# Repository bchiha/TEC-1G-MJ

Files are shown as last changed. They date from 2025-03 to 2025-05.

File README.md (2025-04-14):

## File Links
| File | Description | Version |
|---|---|---|
| [Errata](./Errata.md) | <b>*CRITICAL:*</b> The latest Errata announcements. **Read BEFORE assembly!** | 2/jun/2024 |
| [Assembly Instructions](./Documentation/Assembly/Readme.md) | Instructions on putting the TEC-1G together | 0.2 |
| [Component Overlay](./TEC-1G_Component_Overlay_v1-21.pdf) | Searchable PDF for component placement. | 1.21 |
| [Parts List](./TEC-1G_PartsList_v1-5.pdf) | (Out of date. Needs updating. Use with caution. Always follow schematic.) | 1.5 |
| [BOM Sourcing](./files/TEC-1G_BOM_v1.5.xlsx) | (Out of date. Needs updating. Use with caution. Always follow schematic.) | 1.5 |
| [Schematic](./TEC-1G_Schematic_v1-22.pdf) | See what makes the TEC-1G tick. | 1.22 |
| [PCB Gerbers](./TEC-1G_Gerbers_v1-22_SigEd.zip) | Gerbers of the PCB so you can print your own! | 1.22 |
| [Monitors / ROMs](./ROMs/) | Download and burn the ROMs for your TEC-1G from this link! | 1.5 |
| [MON3 User Guide](./MON3_User_Guide_v1.5.pdf) | The comprehensive User Guide to MON3 | 1.5 |
| [TEC Deck](./TEC-Deck/) | The TEC Deck has multiple Cards that add major functionalityto the TEC-1G! | 1.2 |
| [GPIO Modules](./GPIO/) | See what modules can be attached to the GPIO connector on the LHS of the TEC-1G | 1.0 |
| [TEC Expander](./Expander/) | The Expander finally has the 8x8 LED Array... And it's in RGB! | 1.0 |

## News & Developments

We have added a new section to the GitHub that agregates all the news and new items for the TEC-1G. [Follow this link](https://github.com/MarkJelic/TEC-1G/tree/main/News) for all the latest info.

# TEC-1G Introduction

TEC-1G - A Z80 based single board computer.

The TEC-1G is a direct descendant of the Talking Electronics Computer, known as the TEC-1, which was first published by the Australian electronics hobbyist magazine ["Talking Electronics"](https://www.talkingelectronics.com/te_interactive_index.html) (or simply TE), between 1981 and 1991.

The TEC-1 was developed as a learning computer, designed to teach the basics of how a microprocessor works at the fundamental hardware and software level, and offered the ability to create and run simple programs in Z80 machine code. TE magazine covered the TEC-1 in six installments, known as "Issue 10" to "Issue 15". These magazines can be downloaded freely from the TEC-1 GitHub, located at [tec1group/TE-Magazines](https://github.com/tec1group/TE-Magazines)

Interest in the TEC-1 declined following the winding down of TE through the 1990's, which reflected a general decline in electronics as a hobby in Australia. This, coupled with interest in more advanced 'single chip' microcontrollers saw TEC-1's put aside and the world moved on.

The TEC-1 was revived around 2018 with a release of a reproduction PCB and related peripherals on the Internet. Retro computing has become quite popular of late, and so a an active TEC community has (re)formed through [Facebook](https://www.facebook.com/groups/tec1z80) with new hardware designs, enhanced versions and various expansion options being offered by various contributors within the community.

The 1G builds on both the TEC-1's base and recent history to modernize the overall design, address various design limitations and integrate many of the excellent add-ons into to a single PCB for the first time.

The TEC-1G remains true to the original TE design goals: it is is built using only simple through-hole TTL logic chips so it is easily built and understood by the hobbyist. For the first time, the TEC-1G will also be fully free and open source, in both its hardware and software. The TEC-1G is the ultimate TEC-1!

The 1G has been developed by Mark Jelic with the input of the original designers, John Hardy and Ken Stone, ex-TE staff member Craig Hart, along with contributions from community members Brian Chiha and Ian McLean. Finally, the 1G has also been produced with the blessing of Colin Mitchell, Talking Electronics owner.

## Major Features

- Full TEC-1 hardware and software compatability; runs all previous MONitors without modification
- Flexible memory options; 32K RAM, 16k ROM in default configuration. Up to 64k RAM + 16k ROM supported.
- Support for multiple configuration options and memory types from 2k to 32k memory devices
- RAM write protection for improved software development
- Shadow Memory and bank switching capabilities
- 20x4 LCD screen as primary display device
- Diagnostic & LED bar indicator for system state
- Z80A CPU running at 4.0MHz; 'slow' clock support for older monitors retained
- Full QWERTY MATRIX keyboard & joystick options
- Upgraded key options for onboard hex keypad; supports Gateron Low Profile switches with optional backlighting, as well as standard 12mm tactile buttons
- Improved RESET circuit for reliable start up and system stability
- USB B or 9-12v AC/DC power sources
- Serial interface using an optional FTDI/FT232 adaptor for USB communication with a PC or terminal
- Future support for SD card mass storage interface
- Native Z-80 expansion bus connectors supporting a full range of peripherals
- 'TEC-Deck' expansion connectors for future daughterboards
- 'TEC Expander' port for compatability with existing TEC peripherals
- HALT status LED

## More Documentation [Coming Soon™](/Documentation/readme.md)

TEC-1G Render - Gateron Keys

I'd like to thank PCBWay for sponsoring the ongoing development of modules that are being added to the TEC-1G ecosystem. I'm impressed how proactive they are in finding projects like this one and encourage and foster such development. Thank you, PCBWay!

PCBWay Logo

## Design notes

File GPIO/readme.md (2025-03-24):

# TEC-1G GPIO Connector

## Expansion Modules available for the GPIO Connector
| Module | Description | Version |
|---|---|---|
| [GPIO Protoboard](./Protoboard/) | The protoboard gerbers & design files - Use as a Template!  | 1.3 |
| [GPIO SD Card](./SD-Card/) | Micro SD-Card interface, as well as a general purpose 8Bit input/output board | 1.3 |
| [GPIO RTC](./RTC/) | Real Time Clock and Parameter RAM  | 1.3 |
| [GPIO Printer](./Printer/) | Parallel Printer Interface, and a general purpose 8Bit input/output board  | 1.3 |
| [GPIO New Board!](./) | Add your guesses to the "New GPIO Board" Issue for a chance to win a free kit!  | 1.3 |

#### Adding General Purpose Input/Output capabilities to the TEC-1G, easily.

Version 1.3 of the GPIO connector adds 4 pins to the original 16!

2 pins are spare and can be used by the user for anything they want to propagate up the GPIO stack.

We have also added the Transmit and Receive lines as used by the FTDI module.

These have been added for a NEW board, Coming Soon (tm)!

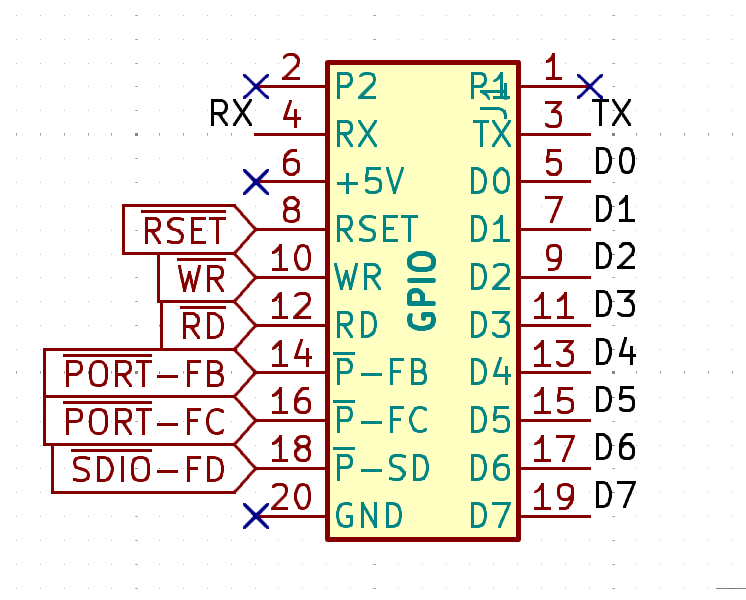
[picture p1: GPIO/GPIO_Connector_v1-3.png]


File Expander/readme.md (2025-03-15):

# TEC Expander

## Expansion Modules available for the TEC Expander
| Module | Description | Version |
|---|---|---|
| [RGB 8x8 Array](./8x8/) | The brand new 8x8 LED Array in full RGB!!  | 1.2 |

The easy way to attach your favourite expansions.



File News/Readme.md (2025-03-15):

# TEC-1G News
--------------------------------------------------------
## Signature Edition Gerbers Released! (15/Mar/2025)
The Signature Edition of the TEC-1G PCB is the final version of the TEC-1G PCB to be released.
The Gerbers can now be downloaded from the root directory of the Repo.

--------------------------------------------------------
## ODE to TEC-1G Song! (12/Mar/2025)
Ken Stone has applied his masterful Musical and AI-Wrangling skills to turn John's poem into a catchy song!

https://github.com/MarkJelic/TEC-1G/blob/main/News/ODE_to_TEC-1G_by_John_Melville_(Ken_Stone).m4a

--------------------------------------------------------
## ODE to TEC-1G by John Melville (11/Mar/2025)
John has penned a brilliant poem about the 1G. Check it out:

https://github.com/MarkJelic/TEC-1G/blob/main/News/Ode_to_1G.md

--------------------------------------------------------
## TEC-1G RGB 8x8 Display (10/Mar/2025)
The first add-on ever developed for the original TEC-1 was an LED 8x8 Matrix Display. 40 years later and the same idea has had new life breathed into it with a full colour RGB module in the tidiest PCB yet design for the 1G, that allows for up to 3 modules chained together. Check the details at<br>

https://github.com/MarkJelic/TEC-1G/tree/main/Expander/8x8

--------------------------------------------------------
## TEC-1G Font Identified! (24/Jun/2024)
The mystery of which font goes into making the iconic TEC-1G logo has been solved by James Elphick.  At first we thought it might have been Posterama 1984 but that is owned by one of the oldest font foundry, Monotype.  James soon found a very close competitor in Montserrat-Alt1 and it is an Open Font typeface.  So in aligning with our ethos, we must have used the Open Source version and we have copied it to this GitHub, in the \Assets folder off the root:<br>

https://github.com/MarkJelic/TEC-1G/tree/main/Assets

--------------------------------------------------------
## Fullisik Mechanical Matrix Keyboard Released! (18/Jun/2024)
Designed by James Elphick, following the design of the Tactile Matrix keyboard, the new Fullisik Mechanical Matrix Keyboard goes on sale today, and is sold out befor the weekend is done! Looks and feels fantastic.

--------------------------------------------------------

## MON3 version 1.5 (7/Jun/2024)
Monitor3 has been upgraded to version 1.5 by Brian Chiha. Get all the details here:<br>
https://github.com/MarkJelic/TEC-1G/tree/main/ROMs/MON3

--------------------------------------------------------
## 7 Segment Bezel by "Fred Nichols" (3/May/2024)

Now this is really cool! Fred Nichols has created a 3D printable Bezel that sits over the 7 segment displays. He has kindly released the STL files so you can download it and print it yourself or get a shop to do that for you. Either way, it makes the TEC-1G look really fancy! [Click on this link](https://github.com/turbo-gecko/TEC/tree/main/3D%20Printing/7%20Seg%20Bezel) to take you to his GitHub!

7Seg Bezel 3 Piece Lit

--------------------------------------------------------
## Dedicated TEC-1G Video Channel Launched (27/Apr/2024)
Yes, we know the documentation isn't complete, and even if it were, there are many amongst us that don't do well learning anything by reading text on a screen. Some of us (raises hand) are visual learners and so videos work well for seeing how things are put together.

And that is exactly what the channel will be about. We will announce new upcoming products, have demos of peripherals available for the TEC-1G, highlight any really cool code released by you, the users, and have documentary type videos showing exactly how any board is put together.

We look forward to your feedback and let us know what you would like to see.

https://www.youtube.com/@TEC-1G

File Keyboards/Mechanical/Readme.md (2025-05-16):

## Fullisik Mechancial Matrix QWERTY Keyboard

Designed by James Elphick

## File Links
| File | Description | Version |
|---|---|---|
| [BOM](TEC-1G_MechMatrix_BOM_v1.0.xlsx) | Bill of Materials |1.0|
| [Assembly Instructions](TEC-1G_Mechanical_Matrix_Keyboard_Assembly_Guide.pdf) | Instructions on putting the keybaord together | 1.0 |

Mechanical Matrix

Kit is available on Tindie: https://www.tindie.com/products/tec1/tec-1g-matrix-mechanical-keyboard/

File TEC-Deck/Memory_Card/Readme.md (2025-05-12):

# TEC Deck Memory Card

- 128K SRAM
- 32K FRAM
- 1x EPROM Programmer
- 1x ColecoVision Cartridge connector

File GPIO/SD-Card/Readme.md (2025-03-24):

# Micro SD Card Support for TEC-1G

| File | Description | Version |
|---|---|---|
| [Errata!]() | If you have a v1.0 ot v1.1 board, please see the Errata below | Fixed in v1.2+ |
| [Schematic](TEC-1G_GPIO_SD-Card_Schematic_v1-4.pdf) | It's a simple circuit, but it's honest storage. | 1.4 |
| [Parts List](./Partslist.md) | What you need to buy (and comes in the Kit) | 1.0 |
| [Assembly Instructions](./Assembly.md) | Coming Soon... | 1.0 |
| [PCB Gerbers](./TEC-1G_GPIO_SD-Card_Gerbers_v1-4.zip) | Download and print your own PCB! | 1.4 |
| [Sample Programs](./Programs/) | Sample code and API reference | 1.0 |

## What Does it Do?
This GPIO expansion can perform two functions, based on whether you have a Micro SD Card module attached to it, or not.
1. With an SD Card module attached, it allows for the use of Micro SD cards to act as your "floppy disc" or "disk drive"
of your TEC-1G.  No more hoping a Cassette Deck is going to be at the right volume. No huge disk drives that take up a lot of room.
Running short of space on your current SD Card? Eject it and insert a new one. Format it for use on the TEC-1G and you are
away with a 128 file capacity.

2. Without an SD Card Module, you can use this board as a General Input & Output board to read up to 8 single inputs
and output to 8 individeual outputs, which could for example, drive a relay board.

## How Does It Work
To use it as an SD Card interface as supported by MON3, the Port Selection jumper must be on $FD. 
If using it as a General Input/Output controller, you have a choice of three (3) ports, which
also means you can stack three of these cards on top of each other and have up to 24 inputs and 24 outputs!

## Why Build It?
Ever wanted your TEC-1 to be your Alarm System? It can be and there used to be a few commercial alrm systems that used the Z80 at their heart!

## How Do You Use It?
The clever people at <b>TEC-1 Inc.</b> will soon release an API as part of MON3.
All this and more, <b>Coming Soon®...</b>

## ERRATA
The first print (Green v1.0) and second print (Blue v1.1) of the GPIO SD-Card board had errors
regarding the Disc Activity LED. The resistor should be tied to +5V, not to GND.

The best way to fix this is to mount the 330 Ohm resistor on the *underside* of the PCB.
Insert the upper leg (closest to the LED) as normal but from the underside. And the other
leg of the resistor should be soldered to Pin 20 of the 74HCT273, which is +5V.

Errata 1

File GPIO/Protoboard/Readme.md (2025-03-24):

# TEC-1G GPIO Protoboard

Have an idea for the TEC-1G and want to quickly prototype it over the weekend?
Then you need one of these!

[Download the Gerbers](./TEC-1G_GPIO_Protoboard_Gerbers_v1-3.zip) and get yourself a set so you're always ready for your creativity to flow.

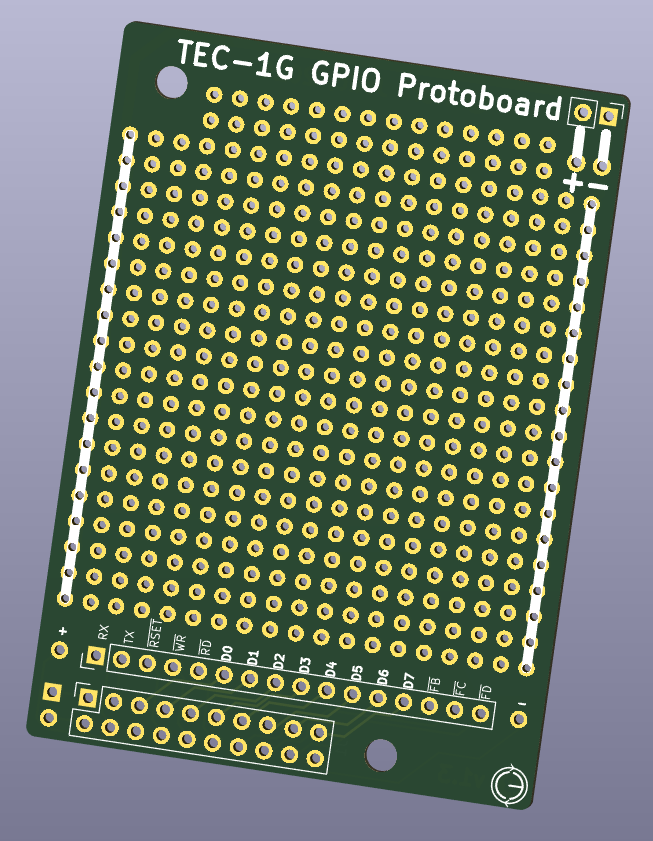
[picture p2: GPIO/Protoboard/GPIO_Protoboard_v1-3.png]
GPIO Protoboard Render


Once you have designed your circuit and tested it out, why not make a PCB and share it with the TECian community!

[Download the KiCAD 8 design files](./TEC-1G_GPIO_Protoboard_v1-3_KiCADv8.zip) of this board, and then removed the parts you don't need,
like all the through hole dots. Make sure you don't move the EdgeCuts, the Mounting Holes and of course the two headers
to ensure they line up with the TEC-1G motherboard.

If you wish to purchase a TEC-1G Proto-Pack which has this and any other Protoboards developed for the TEC-1G,
please check the listing on Tindie, Coming Soon (tm).

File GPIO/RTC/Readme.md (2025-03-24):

# GPIO Real Time Clock (RTC) Board
| File | Description | Version |
|---|---|---|
| [Schematic](TEC-1G_GPIO_RTC_Schematic_v1-0.pdf) | It's a simple circuit, but it's honest timekeeping. | 1.3 |
| [Parts List](./Partslist.md) | What you need to buy (and comes in the Kit) | 1.3 |
| [Assembly Instructions](./Assembly.md) | Watch the Build Video! | 1.0 |
| [PCB Gerbers](./TEC-1G_GPIO-RTC_Gerbers-v1-3.zip) | ZIP file | 1.3 |
| [Sample Programs](./Programs/) | Sample code and API reference | 1.0 |
| [RTC_Programming_notes](./RTC_Programming_notes.md) | Programmers notes | 1.0 |

## Build Video on YouTube!
Watch Mark build the Real Time Clock and come across a problem! https://www.youtube.com/watch?v=rAuSyqJuico<br>
The last 5 minutes of the video are crucial to watch, as there is some code you have to run, after installing the battery, to make the RTC initialise correctly.

## What Does it Do?
It keeps accurate real time, once set, and is battery backed. So even after you switch your TEC-1G off, 
the RTC chip will be powered and will continue to keep accurate time. Oh and it has some battery backed RAM,
a full 31 bytes for you to use for saving variables or settings between power ups. 
We will be calling it PRAM from here on in, short for Parameter RAM, as that is what we will be using it for.

## How Does It Work
The circuit is based around the very cheap and widely used timekeeping chip, the DS1302. 
The DS1302 uses a very simple 3 wire serial interface to communicate with it, so the extra chips you see on the board are basically
just to help with serial communications.

RTC Circuit

## Why Build It?
Since you first built the TEC-1, be it the original like I did, or the latest TEC-1G... Did you look at those six 7 Segment displays
and think:

<b>"Man, that would make a perfect digital clock!"</b>

I did, but there was never a way to keep the clock actually accurate, until now!

But there are other uses as well. With the TEC-1G GPIO SD Card, you will soon be able to save your files... 
But isn't it important to know WHEN you saved that last file, or made chnages to it?
With the RTC Board in place, you can get the correct time and write it to the file so you know when the last time you made edits.

Want more reasons? 
- How long did it take you to solve that Puzzle Game?
- Writing a game that has critical timing or has a time element to make it exciting?
- How about making an automation system for your home, turning on the Christmas lights at sunset?
- Need the sprinklers to come on at a certain time?
- Want to control your model train based on a strict timing schedule?
- What about saving some settings in the battery-backed 31 bytes?

These are just some of the reason you may want an Real Time Clock. 
For me, I want to finally be able to hang up my TEC-1G for the world to see how clever I am with a soldering iron. :)
Oh, and finally be able to answer the question I *always* get: "So what can it do?"<br>
It can be a CLOCK! That's what is can do! Now stop picking on my hobby! ;)

TEC-1G GPIO RTC

## How Do You Use It?
Version 1.4 of MON3 has some new APIs included that allow you to set and retreive the time, as we as set and retreive the battery backed bytes in the DS1302 chip. Brian has also modified the main menu, so that under the Settings Menu, there is an option to configure the Real Time Clock.

<b>Please watch the Last 5 minutes of the video linked above to see the code required to activate the RTC.</b>

Here is the data sheet if you're interested to find out exactly how it works: [DS1302 Spec Sheet](./DS1302_RTC_Timekeeper.pdf)

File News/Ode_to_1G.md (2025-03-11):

# ODE to TEC-1G
by John Melville
<br><br>
Beneath the glow of L.E.D's dance,<br>
A silicon heart is spun—<br>
A symphony of solder trails,<br>
Where old and new are one.<br>
<br>
From TEC-1’s primordial spark,<br>
This circuitscape arose:<br>
32K of RAM’s embrace,<br>
A ROM where knowledge flows.<br>
<br>
Your keys, like runes, press secrets deep,<br>
Hex codes in twilight born,<br>
While LCDs sketch ghostly lines<br>
Of futures yet unworn.<br>

A Z80’s pulse, relentless beat,<br>
Through breadboard veins it streams—<br>
A poet’s chip, unyielding, fierce,<br>
Fueling CP/M dreams.<br>

Oh, artifact of midnight toil,<br>
Of flux and solder fumes—<br>
You bridge the chasm, decade-spanned,<br>
Where retro passion blooms.<br>
<br>
For builders’ hands, your PCB gleams,<br>
A canvas vast and wild—<br>
Where 74-logic gates still sing<br>
To hackers, once a child.<br>
<br>
So here’s to chips that defy the clock,<br>
To code etched line by line—<br>
The TEC-1G, in glory spun:<br>
Our 8-bit shrine.<br>

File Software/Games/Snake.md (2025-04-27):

# Snake
| File | Description |
|---|---|
| [Snake.z80](Snake.z80) | Assembly File |
| [Snake.hex](Snake.hex) | Intel HEX File |

## Description
Snake is a genre of action video games where the player maneuvers the end of a growing line, often themed as a snake. The player must keep the snake from colliding with both other obstacles and itself, which gets harder as the snake lengthens. 

## Requirements
You will need the **RGB 8x8 Matrix Display**

## How to Play
Use the Keys to move the Snake in the direction you want:
- Left:     0
- Right:    2
- Up:       5
- Down:     1

## Loading Instructions
[Download the Intel HEX File](Snake.hex) to your PC, then use a **Serial Terminal Program** like *CoolTerm* to download the HEX file to your TEC-1G via a **USB Cable**.
Use the **MON3 Intel HEX Load** to load the program. After loading, exit the Main Menu by pressing **AD** on the Hexpad or **ESC** on the Matrix Keyboard, which will take you to the address ``4000H``. Press the **GO** button, or the **ENTER** key on the Matrix keyboard to start the program.

## Code
[Download the Assembly Language File](Snake.z80) and examine or change the code and compile your own flavour. If you make any significant changes, consider providing an update to this repo.

### Suggested Modifications
- Length Counter:  Count how many Apples the Snake eats.
- Coloured Display:  Have the Apple in a solid Red

### High Score
Take a photo of of how many Apples your snake has eaten.
We will post results here!

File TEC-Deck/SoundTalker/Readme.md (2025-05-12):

# SoundTalker Audio Card

- SN76489 Sound Geberator
- SP0256A-AL2 Speech Processor
- Mix in standard TEC-1 1-Bit sounds
- Using LM3900 Op Amp

This is Beta 2, using a LM3900 for pre-amp/mixer and amplifier:
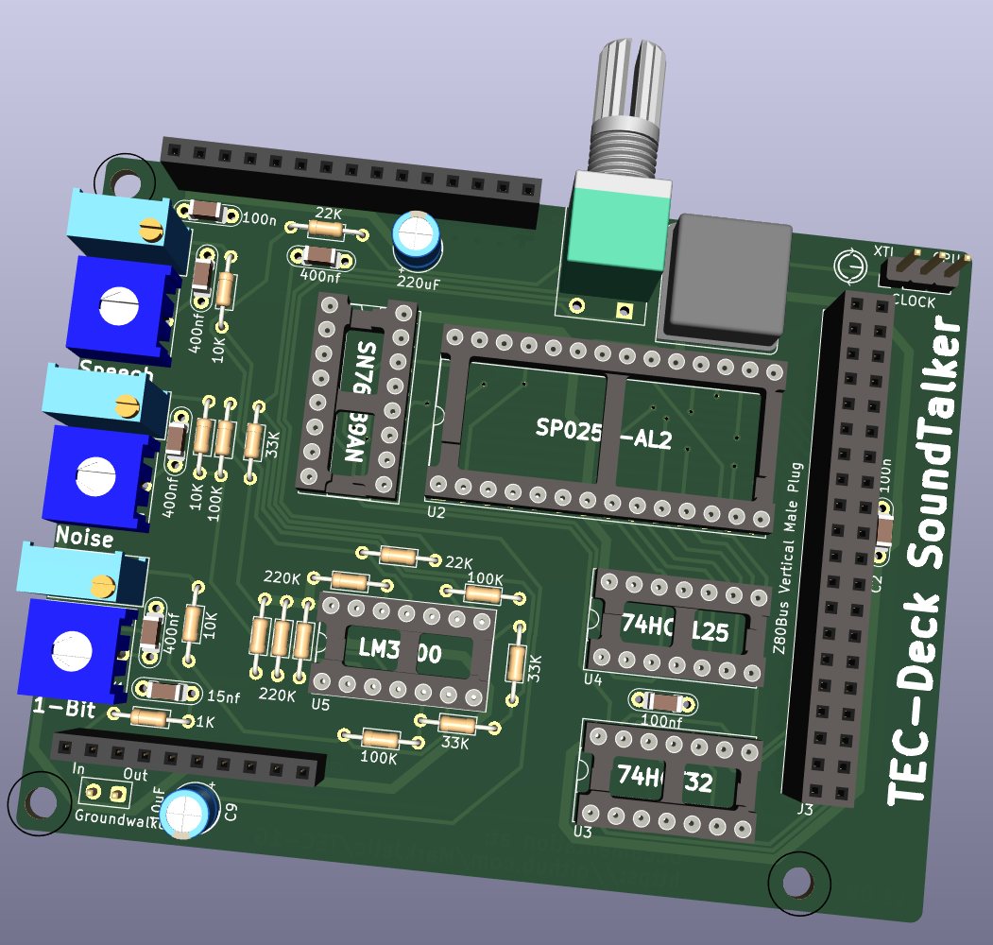
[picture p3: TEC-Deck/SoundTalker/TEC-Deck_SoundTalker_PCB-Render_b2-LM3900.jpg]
TEC-Deck SoundTalker LM3900


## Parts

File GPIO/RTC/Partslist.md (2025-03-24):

# TEC-1G GPIO Real Time Clock (RTC)
### Parts List

| QTY | Part # | Description |
|---|---|---|
| 1 | PCB | TEC-1G GPIO RTC Printed Circuit Board |
| 1 | DS1302 | RTC Timekeeper |
| 1 | Crystal | 32.768 KHz |
| 1 | CR2532 | Battery Holder |
| 1 | 74HCT32 | Quad OR Gates |
| 1 | 74HCT125 | Quad Bus Buffer |
| 1 | 74HCT174 | Hex D-Type Flip-Flops |
| 2 | 100n | Capacitor |
| 1 | 8 pin | DIP Socket |
| 2 | 14 pin | DIP Socket |
| 1 | 16 pin | DIP Socket |
| 1 | 2x10 pin | Long Legged Female Header |
| 1 | 1x2 pin | Long Legged Female Header |
| 2 | 10mm Standoff | M3 Nylon |
| 1 | Screw | M3 Nylon |
| 1 | Nut | M3 Nylon |

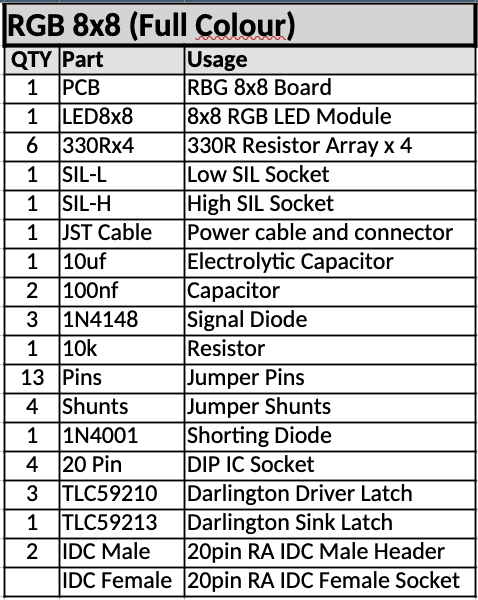
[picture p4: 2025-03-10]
Expander/8x8/TEC-1G_RGB_8x8_BOM.png

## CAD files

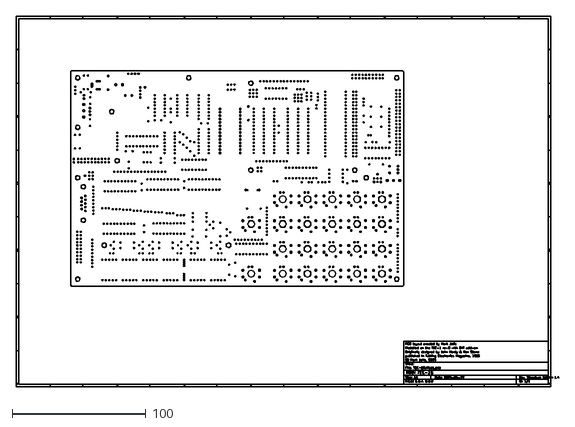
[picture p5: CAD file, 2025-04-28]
files/TEC-1G_Edge-Cuts_v1.4SE.dxf
406.0 x 277.0

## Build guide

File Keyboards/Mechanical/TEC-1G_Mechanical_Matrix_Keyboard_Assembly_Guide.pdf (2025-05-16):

# TEC-1G Mechanical Matrix Fullisik Keyboard

## Assembly Guide

IMPORTANT: Never make ANY assumptions about parts or the build process! Read through this doc first before making any build plans!!

Mechanical Keyboard Overview

The TEC-1G Mechanical Matrix Keyboard is electrically compatible with the Tactile Matrix Keyboard design while adding both mechanical switches (including full-sized stabilised Space, Enter and Shift keys) for comfortable typing and LED lighting circuits for customisation. It also features two Reset switches wired in series to prevent accidental resets.

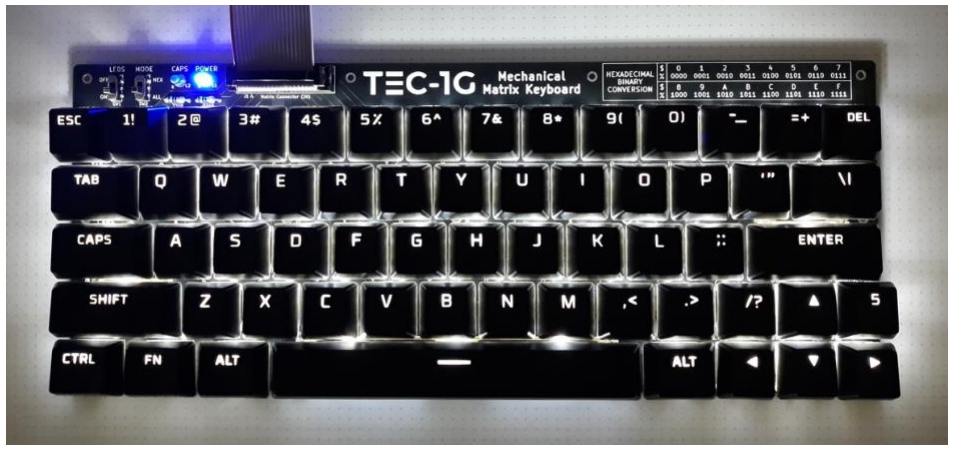
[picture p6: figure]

The PCB can be built into two very different configurations:
1) Cherry-MX switches with Cherry screw-in stabilisers and optional LED lighting, or
2) Gateron Low-Profile (LP) plate-mounted switches with plate-mounted Gateron L.P. stabilisers and optional LED lighting.

Both of these variants have separate sections to highlight important warnings and build advice. Please read the respective section for the version you plan to build.

### 1. Cherry Variant

The Cherry variant is a more standard and affordable mechanical keyboard, designed to be built with:
- Any 5-pin(**Note 1.1) Cherry-compatible mechanical switch (tactile, linear or clicky)
- Cherry-compatible PCB screw-in stabilisers
- Any Cherry-compatible keycap set

Most off-the-shelf mechanical keyboards are Cherry-compatible, allowing users to borrow keycaps from other keyboards for more customisation and cost reduction.

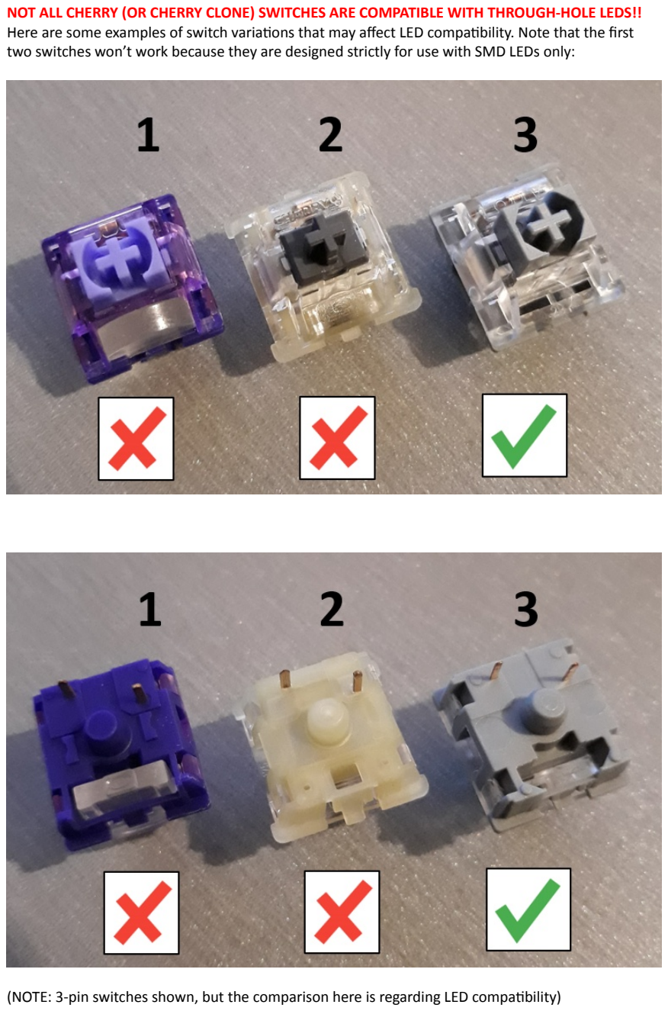
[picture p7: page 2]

NOT ALL CHERRY (OR CHERRY CLONE) SWITCHES ARE COMPATIBLE WITH THROUGH-HOLE LEDS!! Here are some examples of switch variations that may affect LED compatibility. Note that the first two switches won’t work because they are designed strictly for use with SMD LEDs only:

(NOTE: 3-pin switches shown, but the comparison here is regarding LED compatibility)

The appropriate build steps for a Cherry variant keyboard are:
1. Solder on the R3 – R64 0805 SMD resistors on the back of the PCB (ONLY if adding the optional LEDs).
NOTE: This is preferably done with a hotplate or hot-air station. However if using a standard soldering iron, this is done by holding the SMD resistor with tweezers and dabbing solder on one end, then soldering the other end when it is securely held in place.
2. Solder in the two through-hole resistors, matrix 20-pin connector and LED Power/Mode switches.
3. PRO TIP: Test all your LEDs now! By applying +5V/GND to the board, you can one-by-one loosely position each LED in place and check they lights up. Put them aside and don’t solder them just yet! Also use this technique to verify that the SMD resistors and mode switches are all working properly.
4. Position and solder all switches EXCEPT the Shift, Enter and Space switches (which coincidentally use stabilisers).
5. Screw in the stabilisers(**Note 1.2).
6. Use the stabilised keycaps to locate and solder in the Shift, Enter and Space switches. This is to ensure these switches are aligned properly and don’t have “sticking” issues.
7. Solder in the through-hole LEDs from the top side of the switches.
8. Plug in the keyboard and check that the switches and LED lights are working.
9. Finally, add the complete keycap set.

**NOTE 1.1 – 3-pin switches may be substituted however they are very difficult to position individually due to intentionally very wide design tolerances.

**NOTE 1.2 – Lubricating your stabilisers is optional, but can significantly reduce rattle. Some stabilisers may be supplied with inadequate lubricant, or even none at all. Many guides are available online that discuss what lube is most suitable and how to apply it. Even if your keyboard is already built, screw-in stabilisers can be easily removed and lubed afterwards.

### 2. Gateron Low-Profile Variant

The Gateron LP variant is a higher-end low profile keyboard, designed to be built with:
- Gateron KS-33 low profile switches (tactile, linear or clicky)
- Gateron low profile plate-mounted stabilisers
- The TEC-1G mechanical matrix keyboard plate (specifically for Gateron LP variant)
- Gateron LP compatible keycaps

Users MUST be aware that the Gateron LP variant is both higher cost and more difficult to build/repair, as such it is less suitable for beginners, however it provides the benefits of a low-profile design and a higher-end plate-mounted typing experience.

The appropriate build steps for a Gateron LP variant keyboard are:
1. Remove the PCB stabiliser cutouts by clipping the mousebites and removing the inserts as shown. This mod is done so that the stabiliser housings can protrude through the PCB (test fitting as shown to check clearances is recommended).

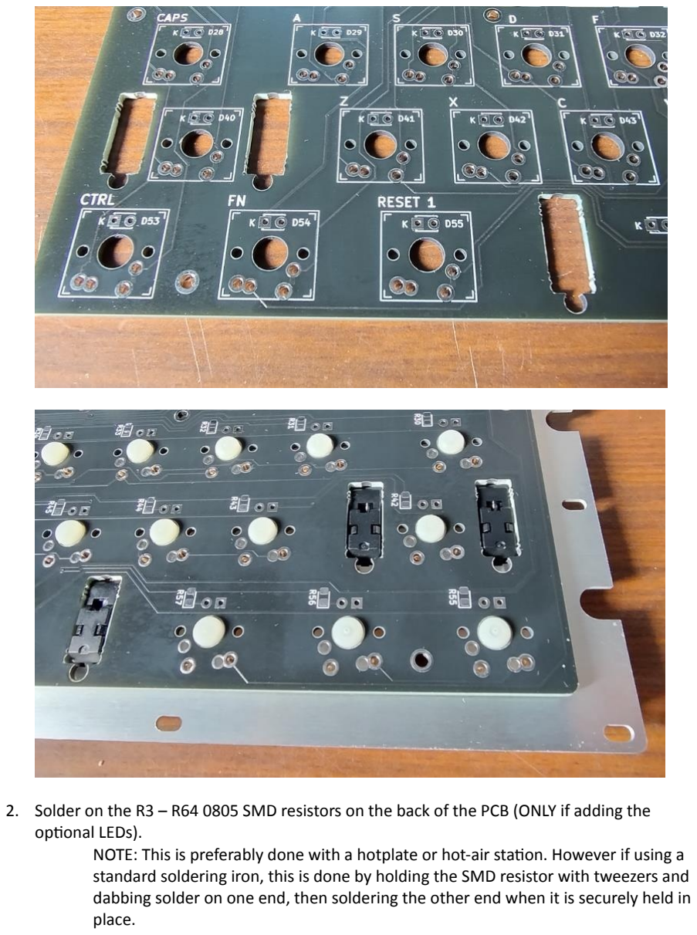
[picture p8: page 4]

2. Solder on the R3 – R64 0805 SMD resistors on the back of the PCB (ONLY if adding the optional LEDs).
NOTE: This is preferably done with a hotplate or hot-air station. However if using a standard soldering iron, this is done by holding the SMD resistor with tweezers and dabbing solder on one end, then soldering the other end when it is securely held in place.

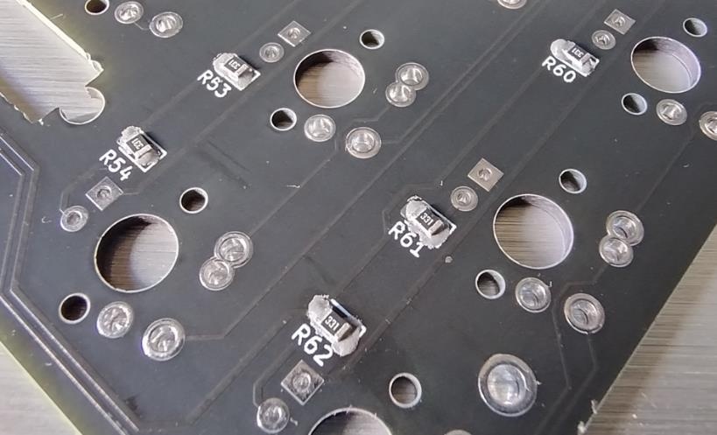
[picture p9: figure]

3. Solder in the two through-hole resistors, matrix 20-pin connector and LED Power/Mode switches.
4. PRO TIP: Test all your LEDs now! By applying +5V/GND to the board, you can one-by-one loosely position each LED in place and check they lights up. Put them aside and don’t solder them just yet! Also use this technique to verify that the SMD resistors and mode switches are all working properly.
5. Clip the three plate-mount Gateron LP stabilisers into the plate.
NOTE – The stabilisers will not be coming back out again after this step!!! It is highly recommended that you do any stabiliser modifications (including lubricating) BEFORE the plate is in position over the PCB. Once the switches are soldered, the stabilisers are no longer accessible without desoldering at least the stabilised switch.
6. Solder in one switch (with LED) at each corner to hold the plate into its final position.
7. Doing one LED + switch at a time, snap in and solder each switch into position.
NOTE – Solder all switches EXCEPT the Shift, Enter and Space switches (which use stabilisers).
8. Install the stabilised keycaps and solder in the Shift, Enter and Space switches. This is to ensure these switches are aligned properly and don’t have “sticking” issues.
9. Plug in the keyboard and check that the switches and LED lights are working.
10. Finally, add the complete keycap set.

Pro Tips For Best Results:

- Top-mounted LEDs are more effective at making keycap characters shine bright. Under-switch LEDs will still work but the contrast isn’t as strong.
- Spend plenty of time making sure the switches are aligned perfectly before soldering, since any slight rotation will become obvious with the keycap clearances.
- Cheap keycaps often have very inconsistent clearances, which can still make the keys look misaligned even if the switches are perfectly aligned.

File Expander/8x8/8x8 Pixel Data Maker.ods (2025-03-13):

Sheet: Mario
 |  |  |  |  |  |  |  | RED |  |  |  |  |  |  |  | GREEN |  |  |  |  |  |  |  | BLUE
 |  | b | b | b | b |  |  | 0 | 0 | 0 | 0 | 0 | 0 | 0 | 0 | 0 | 0 | 0 | 0 | 0 | 0 | 0 | 0 | 0 | 0 | 1 | 1 | 1 | 1 | 0 | 0
 |  | b | b | b | w | b |  | 0 | 0 | 0 | 0 | 0 | 1 | 0 | 0 | 0 | 0 | 0 | 0 | 0 | 1 | 0 | 0 | 0 | 0 | 1 | 1 | 1 | 1 | 1 | 0
 |  | y | a | y | a |  |  | 0 | 0 | 1 | 0 | 1 | 0 | 0 | 0 | 0 | 0 | 1 | 1 | 1 | 1 | 0 | 0 | 0 | 0 | 0 | 1 | 0 | 1 | 0 | 0
 |  | y | y | p | y |  |  | 0 | 0 | 1 | 1 | 1 | 1 | 0 | 0 | 0 | 0 | 1 | 1 | 0 | 1 | 0 | 0 | 0 | 0 | 0 | 0 | 1 | 0 | 0 | 0
y | b | r | b | b | r | b | y | 1 | 0 | 1 | 0 | 0 | 1 | 0 | 1 | 1 | 0 | 0 | 0 | 0 | 0 | 0 | 1 | 0 | 1 | 0 | 1 | 1 | 0 | 1 | 0
 |  | r | r | r | r |  |  | 0 | 0 | 1 | 1 | 1 | 1 | 0 | 0 | 0 | 0 | 0 | 0 | 0 | 0 | 0 | 0 | 0 | 0 | 0 | 0 | 0 | 0 | 0 | 0
 |  | r | r | r | r |  |  | 0 | 0 | 1 | 1 | 1 | 1 | 0 | 0 | 0 | 0 | 0 | 0 | 0 | 0 | 0 | 0 | 0 | 0 | 0 | 0 | 0 | 0 | 0 | 0
 |  | p |  |  | p |  |  | 0 | 0 | 1 | 0 | 0 | 1 | 0 | 0 | 0 | 0 | 0 | 0 | 0 | 0 | 0 | 0 | 0 | 0 | 1 | 0 | 0 | 1 | 0 | 0
.dw $00, $04, $28, $3C, $A5, $3C, $3C, $24 |  |  |  |  |  |  |  | $00 |  |  |  |  |  |  |  | $00 |  |  |  |  |  |  |  | $3C
.dw $00, $04, $3C, $34, $81, $00, $00, $00 |  |  |  |  |  |  |  | $04 |  |  |  |  |  |  |  | $04 |  |  |  |  |  |  |  | $3E
.dw $3C, $3E, $14, $08, $5A, $00, $00, $24 |  |  |  |  |  |  |  | $28 |  |  |  |  |  |  |  | $3C |  |  |  |  |  |  |  | $14
 |  |  |  |  |  |  |  | $3C |  |  |  |  |  |  |  | $34 |  |  |  |  |  |  |  | $08
 |  |  |  |  |  |  |  | $A5 |  |  |  |  |  |  |  | $81 |  |  |  |  |  |  |  | $5A
 |  |  |  |  |  |  |  | $3C |  |  |  |  |  |  |  | $00 |  |  |  |  |  |  |  | $00
 |  |  |  |  |  |  |  | $3C |  |  |  |  |  |  |  | $00 |  |  |  |  |  |  |  | $00
 |  |  |  |  |  |  |  | $24 |  |  |  |  |  |  |  | $00 |  |  |  |  |  |  |  | $24

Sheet: Spacey
 |  |  |  |  |  |  |  | RED |  |  |  |  |  |  |  | GREEN |  |  |  |  |  |  |  | BLUE
 |  | g |  |  | g |  |  | 0 | 0 | 0 | 0 | 0 | 0 | 0 | 0 | 0 | 0 | 1 | 0 | 0 | 1 | 0 | 0 | 0 | 0 | 0 | 0 | 0 | 0 | 0 | 0
 | g | g | g | g | g | g |  | 0 | 0 | 0 | 0 | 0 | 0 | 0 | 0 | 0 | 1 | 1 | 1 | 1 | 1 | 1 | 0 | 0 | 0 | 0 | 0 | 0 | 0 | 0 | 0
g | g | g | g | g | g | g | g | 0 | 0 | 0 | 0 | 0 | 0 | 0 | 0 | 1 | 1 | 1 | 1 | 1 | 1 | 1 | 1 | 0 | 0 | 0 | 0 | 0 | 0 | 0 | 0
g | g | r | g | g | r | g | g | 0 | 0 | 1 | 0 | 0 | 1 | 0 | 0 | 1 | 1 | 0 | 1 | 1 | 0 | 1 | 1 | 0 | 0 | 0 | 0 | 0 | 0 | 0 | 0
 | g | g | g | g | g | g |  | 0 | 0 | 0 | 0 | 0 | 0 | 0 | 0 | 0 | 1 | 1 | 1 | 1 | 1 | 1 | 0 | 0 | 0 | 0 | 0 | 0 | 0 | 0 | 0
 | g | w | w | w | w | g |  | 0 | 0 | 1 | 1 | 1 | 1 | 0 | 0 | 0 | 1 | 1 | 1 | 1 | 1 | 1 | 0 | 0 | 0 | 1 | 1 | 1 | 1 | 0 | 0
g |  | g | g | g | g |  | g | 0 | 0 | 0 | 0 | 0 | 0 | 0 | 0 | 1 | 0 | 1 | 1 | 1 | 1 | 0 | 1 | 0 | 0 | 0 | 0 | 0 | 0 | 0 | 0
g |  |  |  |  |  |  | g | 0 | 0 | 0 | 0 | 0 | 0 | 0 | 0 | 1 | 0 | 0 | 0 | 0 | 0 | 0 | 1 | 0 | 0 | 0 | 0 | 0 | 0 | 0 | 0
.dw $00, $00, $00, $24, $00, $3C, $00, $00 |  |  |  |  |  |  |  | $00 |  |  |  |  |  |  |  | $24 |  |  |  |  |  |  |  | $00
.dw $24, $7E, $FF, $DB, $7E, $7E, $BD, $81 |  |  |  |  |  |  |  | $00 |  |  |  |  |  |  |  | $7E |  |  |  |  |  |  |  | $00
.dw $00, $00, $00, $00, $00, $3C, $00, $00 |  |  |  |  |  |  |  | $00 |  |  |  |  |  |  |  | $FF |  |  |  |  |  |  |  | $00
 |  |  |  |  |  |  |  | $24 |  |  |  |  |  |  |  | $DB |  |  |  |  |  |  |  | $00
 |  |  |  |  |  |  |  | $00 |  |  |  |  |  |  |  | $7E |  |  |  |  |  |  |  | $00
 |  |  |  |  |  |  |  | $3C |  |  |  |  |  |  |  | $7E |  |  |  |  |  |  |  | $3C
 |  |  |  |  |  |  |  | $00 |  |  |  |  |  |  |  | $BD |  |  |  |  |  |  |  | $00
 |  |  |  |  |  |  |  | $00 |  |  |  |  |  |  |  | $81 |  |  |  |  |  |  |  | $00

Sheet: Superman
 |  |  |  |  |  |  |  | RED |  |  |  |  |  |  |  | GREEN |  |  |  |  |  |  |  | BLUE
 |  |  |  |  | w |  |  | 0 | 0 | 0 | 0 | 0 | 1 | 0 | 0 | 0 | 0 | 0 | 0 | 0 | 1 | 0 | 0 | 0 | 0 | 0 | 0 | 0 | 1 | 0 | 0
 |  |  |  | w | w |  |  | 0 | 0 | 0 | 0 | 1 | 1 | 0 | 0 | 0 | 0 | 0 | 0 | 1 | 1 | 0 | 0 | 0 | 0 | 0 | 0 | 1 | 1 | 0 | 0
 |  | r | a | r | y | r |  | 0 | 0 | 1 | 0 | 1 | 1 | 1 | 0 | 0 | 0 | 0 | 1 | 0 | 1 | 0 | 0 | 0 | 0 | 0 | 1 | 0 | 0 | 0 | 0
r | r | a | a | a | r | a |  | 1 | 1 | 0 | 0 | 0 | 1 | 0 | 0 | 0 | 0 | 1 | 1 | 1 | 0 | 1 | 0 | 0 | 0 | 1 | 1 | 1 | 0 | 1 | 0
p | p | w | p | a | a |  | w | 1 | 1 | 1 | 1 | 0 | 0 | 0 | 1 | 0 | 0 | 1 | 0 | 1 | 1 | 0 | 1 | 1 | 1 | 1 | 1 | 1 | 1 | 0 | 1
 | p | p | p | r | p |  |  | 0 | 1 | 1 | 1 | 1 | 1 | 0 | 0 | 0 | 0 | 0 | 0 | 0 | 0 | 0 | 0 | 0 | 1 | 1 | 1 | 0 | 1 | 0 | 0
 |  |  | a | b |  | b |  | 0 | 0 | 0 | 0 | 0 | 0 | 0 | 0 | 0 | 0 | 0 | 1 | 0 | 0 | 0 | 0 | 0 | 0 | 0 | 1 | 1 | 0 | 1 | 0
 |  |  | r |  |  | r |  | 0 | 0 | 0 | 1 | 0 | 0 | 1 | 0 | 0 | 0 | 0 | 0 | 0 | 0 | 0 | 0 | 0 | 0 | 0 | 0 | 0 | 0 | 0 | 0
.dw $04, $0C, $2E, $C4, $F1, $7C, $00, $12 |  |  |  |  |  |  |  | $04 |  |  |  |  |  |  |  | $04 |  |  |  |  |  |  |  | $04
.dw $04, $0C, $14, $3A, $2D, $00, $10, $00 |  |  |  |  |  |  |  | $0C |  |  |  |  |  |  |  | $0C |  |  |  |  |  |  |  | $0C
.dw $04, $0C, $10, $3A, $FD, $74, $1A, $00 |  |  |  |  |  |  |  | $2E |  |  |  |  |  |  |  | $14 |  |  |  |  |  |  |  | $10
 |  |  |  |  |  |  |  | $C4 |  |  |  |  |  |  |  | $3A |  |  |  |  |  |  |  | $3A
 |  |  |  |  |  |  |  | $F1 |  |  |  |  |  |  |  | $2D |  |  |  |  |  |  |  | $FD
 |  |  |  |  |  |  |  | $7C |  |  |  |  |  |  |  | $00 |  |  |  |  |  |  |  | $74
 |  |  |  |  |  |  |  | $00 |  |  |  |  |  |  |  | $10 |  |  |  |  |  |  |  | $1A
 |  |  |  |  |  |  |  | $12 |  |  |  |  |  |  |  | $00 |  |  |  |  |  |  |  | $00

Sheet: Ghost
 |  |  |  |  |  |  |  | RED |  |  |  |  |  |  |  | GREEN |  |  |  |  |  |  |  | BLUE
 |  | a | a | a | b |  |  | 0 | 0 | 0 | 0 | 0 | 0 | 0 | 0 | 0 | 0 | 1 | 1 | 1 | 0 | 0 | 0 | 0 | 0 | 1 | 1 | 1 | 1 | 0 | 0
 | a | a | a | a | a | b |  | 0 | 0 | 0 | 0 | 0 | 0 | 0 | 0 | 0 | 1 | 1 | 1 | 1 | 1 | 0 | 0 | 0 | 1 | 1 | 1 | 1 | 1 | 1 | 0
a | a |  | w | a |  | w | b | 0 | 0 | 0 | 1 | 0 | 0 | 1 | 0 | 1 | 1 | 0 | 1 | 1 | 0 | 1 | 0 | 1 | 1 | 0 | 1 | 1 | 0 | 1 | 1
a | a | w | w | a | w | w | b | 0 | 0 | 1 | 1 | 0 | 1 | 1 | 0 | 1 | 1 | 1 | 1 | 1 | 1 | 1 | 0 | 1 | 1 | 1 | 1 | 1 | 1 | 1 | 1
a | a | a | a | a | a | b | b | 0 | 0 | 0 | 0 | 0 | 0 | 0 | 0 | 1 | 1 | 1 | 1 | 1 | 1 | 0 | 0 | 1 | 1 | 1 | 1 | 1 | 1 | 1 | 1
a | a | a | a | a | a | b | b | 0 | 0 | 0 | 0 | 0 | 0 | 0 | 0 | 1 | 1 | 1 | 1 | 1 | 1 | 0 | 0 | 1 | 1 | 1 | 1 | 1 | 1 | 1 | 1
a | a | a | a | a | a | b | b | 0 | 0 | 0 | 0 | 0 | 0 | 0 | 0 | 1 | 1 | 1 | 1 | 1 | 1 | 0 | 0 | 1 | 1 | 1 | 1 | 1 | 1 | 1 | 1
a |  | a | a |  | a | b |  | 0 | 0 | 0 | 0 | 0 | 0 | 0 | 0 | 1 | 0 | 1 | 1 | 0 | 1 | 0 | 0 | 1 | 0 | 1 | 1 | 0 | 1 | 1 | 0
.dw $00, $00, $12, $36, $00, $00, $00, $00 |  |  |  |  |  |  |  | $00 |  |  |  |  |  |  |  | $38 |  |  |  |  |  |  |  | $3C
.dw $38, $7C, $DA, $FE, $FC, $FC, $FC, $B4 |  |  |  |  |  |  |  | $00 |  |  |  |  |  |  |  | $7C |  |  |  |  |  |  |  | $7E
.dw $3C, $7E, $DB, $FF, $FF, $FF, $FF, $B6 |  |  |  |  |  |  |  | $12 |  |  |  |  |  |  |  | $DA |  |  |  |  |  |  |  | $DB
 |  |  |  |  |  |  |  | $36 |  |  |  |  |  |  |  | $FE |  |  |  |  |  |  |  | $FF
 |  |  |  |  |  |  |  | $00 |  |  |  |  |  |  |  | $FC |  |  |  |  |  |  |  | $FF
 |  |  |  |  |  |  |  | $00 |  |  |  |  |  |  |  | $FC |  |  |  |  |  |  |  | $FF
 |  |  |  |  |  |  |  | $00 |  |  |  |  |  |  |  | $FC |  |  |  |  |  |  |  | $FF
 |  |  |  |  |  |  |  | $00 |  |  |  |  |  |  |  | $B4 |  |  |  |  |  |  |  | $B6

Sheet: Cherry
 |  |  |  |  |  |  |  | RED |  |  |  |  |  |  |  | GREEN |  |  |  |  |  |  |  | BLUE
 |  |  |  | g | g | g |  | 0 | 0 | 0 | 0 | 0 | 0 | 0 | 0 | 0 | 0 | 0 | 0 | 1 | 1 | 1 | 0 | 0 | 0 | 0 | 0 | 0 | 0 | 0 | 0
 |  |  | g |  | g |  |  | 0 | 0 | 0 | 0 | 0 | 0 | 0 | 0 | 0 | 0 | 0 | 1 | 0 | 1 | 0 | 0 | 0 | 0 | 0 | 0 | 0 | 0 | 0 | 0
 |  | g |  |  | g |  |  | 0 | 0 | 0 | 0 | 0 | 0 | 0 | 0 | 0 | 0 | 1 | 0 | 0 | 1 | 0 | 0 | 0 | 0 | 0 | 0 | 0 | 0 | 0 | 0
 |  | g |  |  | r | r |  | 0 | 0 | 0 | 0 | 0 | 1 | 1 | 0 | 0 | 0 | 1 | 0 | 0 | 0 | 0 | 0 | 0 | 0 | 0 | 0 | 0 | 0 | 0 | 0
 | r | r |  | r | r | w | r | 0 | 1 | 1 | 0 | 1 | 1 | 1 | 1 | 0 | 0 | 0 | 0 | 0 | 0 | 1 | 0 | 0 | 0 | 0 | 0 | 0 | 0 | 1 | 0
r | r | w | r |  | r | r | r | 1 | 1 | 1 | 1 | 0 | 1 | 1 | 1 | 0 | 0 | 1 | 0 | 0 | 0 | 0 | 0 | 0 | 0 | 1 | 0 | 0 | 0 | 0 | 0
r | r | r | r |  | r | r |  | 1 | 1 | 1 | 1 | 0 | 1 | 1 | 0 | 0 | 0 | 0 | 0 | 0 | 0 | 0 | 0 | 0 | 0 | 0 | 0 | 0 | 0 | 0 | 0
 | r | r |  |  |  |  |  | 0 | 1 | 1 | 0 | 0 | 0 | 0 | 0 | 0 | 0 | 0 | 0 | 0 | 0 | 0 | 0 | 0 | 0 | 0 | 0 | 0 | 0 | 0 | 0
.dw $00, $00, $00, $06, $6F, $F7, $F6, $60 |  |  |  |  |  |  |  | $00 |  |  |  |  |  |  |  | $0E |  |  |  |  |  |  |  | $00
.dw $0E, $14, $24, $20, $02, $20, $00, $00 |  |  |  |  |  |  |  | $00 |  |  |  |  |  |  |  | $14 |  |  |  |  |  |  |  | $00
.dw $00, $00, $00, $00, $02, $20, $00, $00 |  |  |  |  |  |  |  | $00 |  |  |  |  |  |  |  | $24 |  |  |  |  |  |  |  | $00
 |  |  |  |  |  |  |  | $06 |  |  |  |  |  |  |  | $20 |  |  |  |  |  |  |  | $00
 |  |  |  |  |  |  |  | $6F |  |  |  |  |  |  |  | $02 |  |  |  |  |  |  |  | $02
 |  |  |  |  |  |  |  | $F7 |  |  |  |  |  |  |  | $20 |  |  |  |  |  |  |  | $20
 |  |  |  |  |  |  |  | $F6 |  |  |  |  |  |  |  | $00 |  |  |  |  |  |  |  | $00
 |  |  |  |  |  |  |  | $60 |  |  |  |  |  |  |  | $00 |  |  |  |  |  |  |  | $00

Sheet: Gay
 |  |  |  | RED |  |  |  |  |  |  |  | GREEN |  |  |  |  |  |  |  | BLUE
w | w | w | w | 1 | 0 | 1 | 0 | 1 | 0 | 1 | 0 | 1 | 0 | 1 | 0 | 1 | 0 | 1 | 0 | 1 | 0 | 1 | 0 | 1 | 0 | 1 | 0
w | w | w | w | 1 | 0 | 1 | 0 | 1 | 0 | 1 | 0 | 1 | 0 | 1 | 0 | 1 | 0 | 1 | 0 | 1 | 0 | 1 | 0 | 1 | 0 | 1 | 0
w | w | w | w | 1 | 0 | 1 | 0 | 1 | 0 | 1 | 0 | 1 | 0 | 1 | 0 | 1 | 0 | 1 | 0 | 1 | 0 | 1 | 0 | 1 | 0 | 1 | 0
w | w | w | w | 1 | 0 | 1 | 0 | 1 | 0 | 1 | 0 | 1 | 0 | 1 | 0 | 1 | 0 | 1 | 0 | 1 | 0 | 1 | 0 | 1 | 0 | 1 | 0
w | w | w | w | 1 | 0 | 1 | 0 | 1 | 0 | 1 | 0 | 1 | 0 | 1 | 0 | 1 | 0 | 1 | 0 | 1 | 0 | 1 | 0 | 1 | 0 | 1 | 0
w | w | w | w | 1 | 0 | 1 | 0 | 1 | 0 | 1 | 0 | 1 | 0 | 1 | 0 | 1 | 0 | 1 | 0 | 1 | 0 | 1 | 0 | 1 | 0 | 1 | 0
w | w | w | w | 1 | 0 | 1 | 0 | 1 | 0 | 1 | 0 | 1 | 0 | 1 | 0 | 1 | 0 | 1 | 0 | 1 | 0 | 1 | 0 | 1 | 0 | 1 | 0
w | w | w | w | 1 | 0 | 1 | 0 | 1 | 0 | 1 | 0 | 1 | 0 | 1 | 0 | 1 | 0 | 1 | 0 | 1 | 0 | 1 | 0 | 1 | 0 | 1 | 0
.db $AA, $AA, $AA, $AA, $AA, $AA, $AA, $AA |  |  |  | $AA |  |  |  |  |  |  |  | $AA |  |  |  |  |  |  |  | $AA
.db $AA, $AA, $AA, $AA, $AA, $AA, $AA, $AA |  |  |  | $AA |  |  |  |  |  |  |  | $AA |  |  |  |  |  |  |  | $AA
.db $AA, $AA, $AA, $AA, $AA, $AA, $AA, $AA |  |  |  | $AA |  |  |  |  |  |  |  | $AA |  |  |  |  |  |  |  | $AA
 |  |  |  | $AA |  |  |  |  |  |  |  | $AA |  |  |  |  |  |  |  | $AA
 |  |  |  | $AA |  |  |  |  |  |  |  | $AA |  |  |  |  |  |  |  | $AA
 |  |  |  | $AA |  |  |  |  |  |  |  | $AA |  |  |  |  |  |  |  | $AA
 |  |  |  | $AA |  |  |  |  |  |  |  | $AA |  |  |  |  |  |  |  | $AA
 |  |  |  | $AA |  |  |  |  |  |  |  | $AA |  |  |  |  |  |  |  | $AA
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

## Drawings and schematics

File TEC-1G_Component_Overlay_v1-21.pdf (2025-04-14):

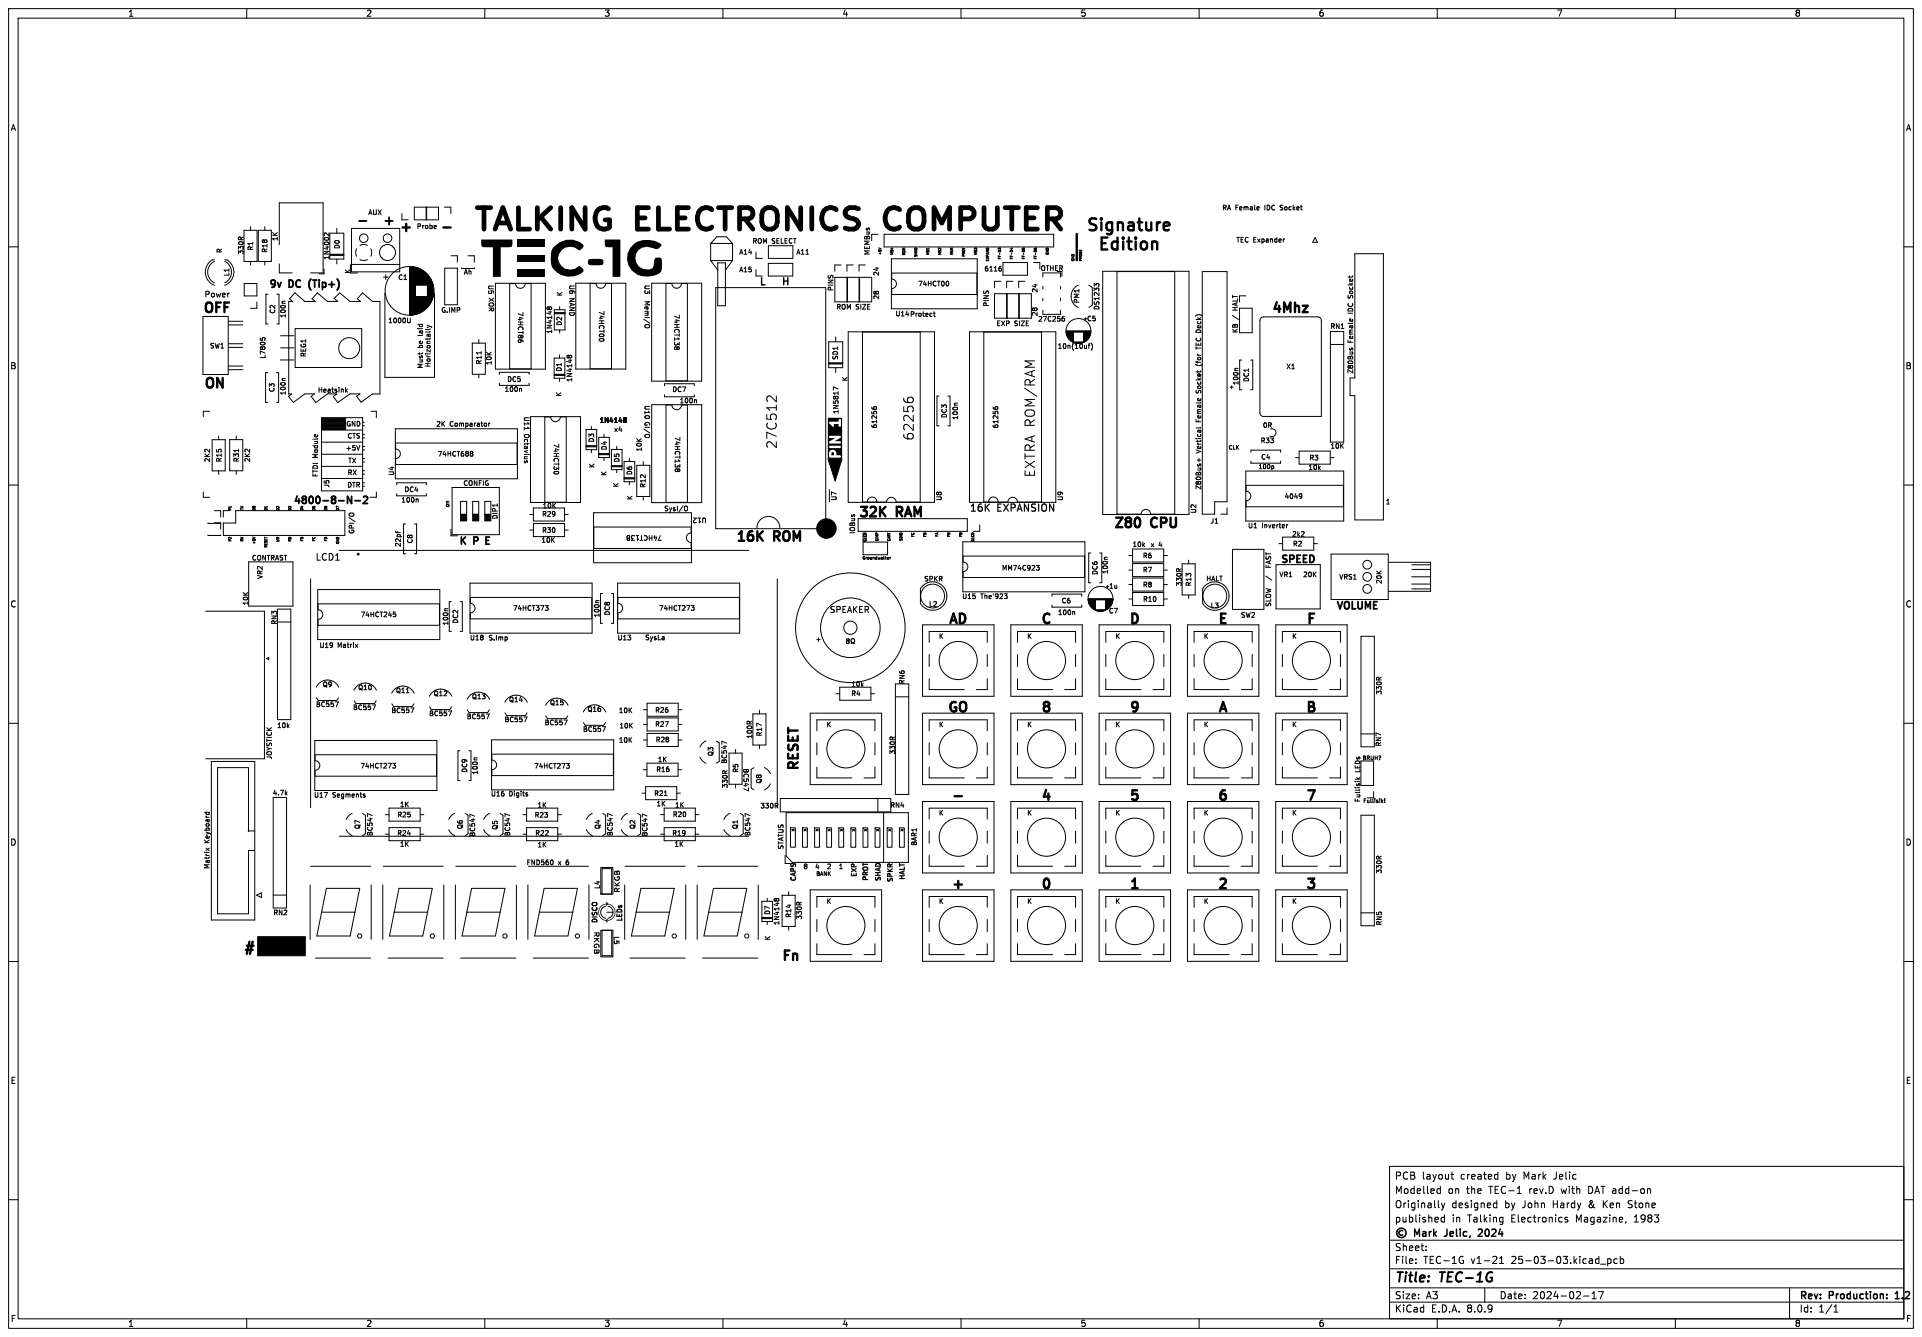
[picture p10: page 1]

TEC Expander RA Female IDC Socket SD1 1N5817 K

- EXP GND PROBE PROT LEDs

J1 Z80Bus+ Vertical Female Socket (for TEC Deck)

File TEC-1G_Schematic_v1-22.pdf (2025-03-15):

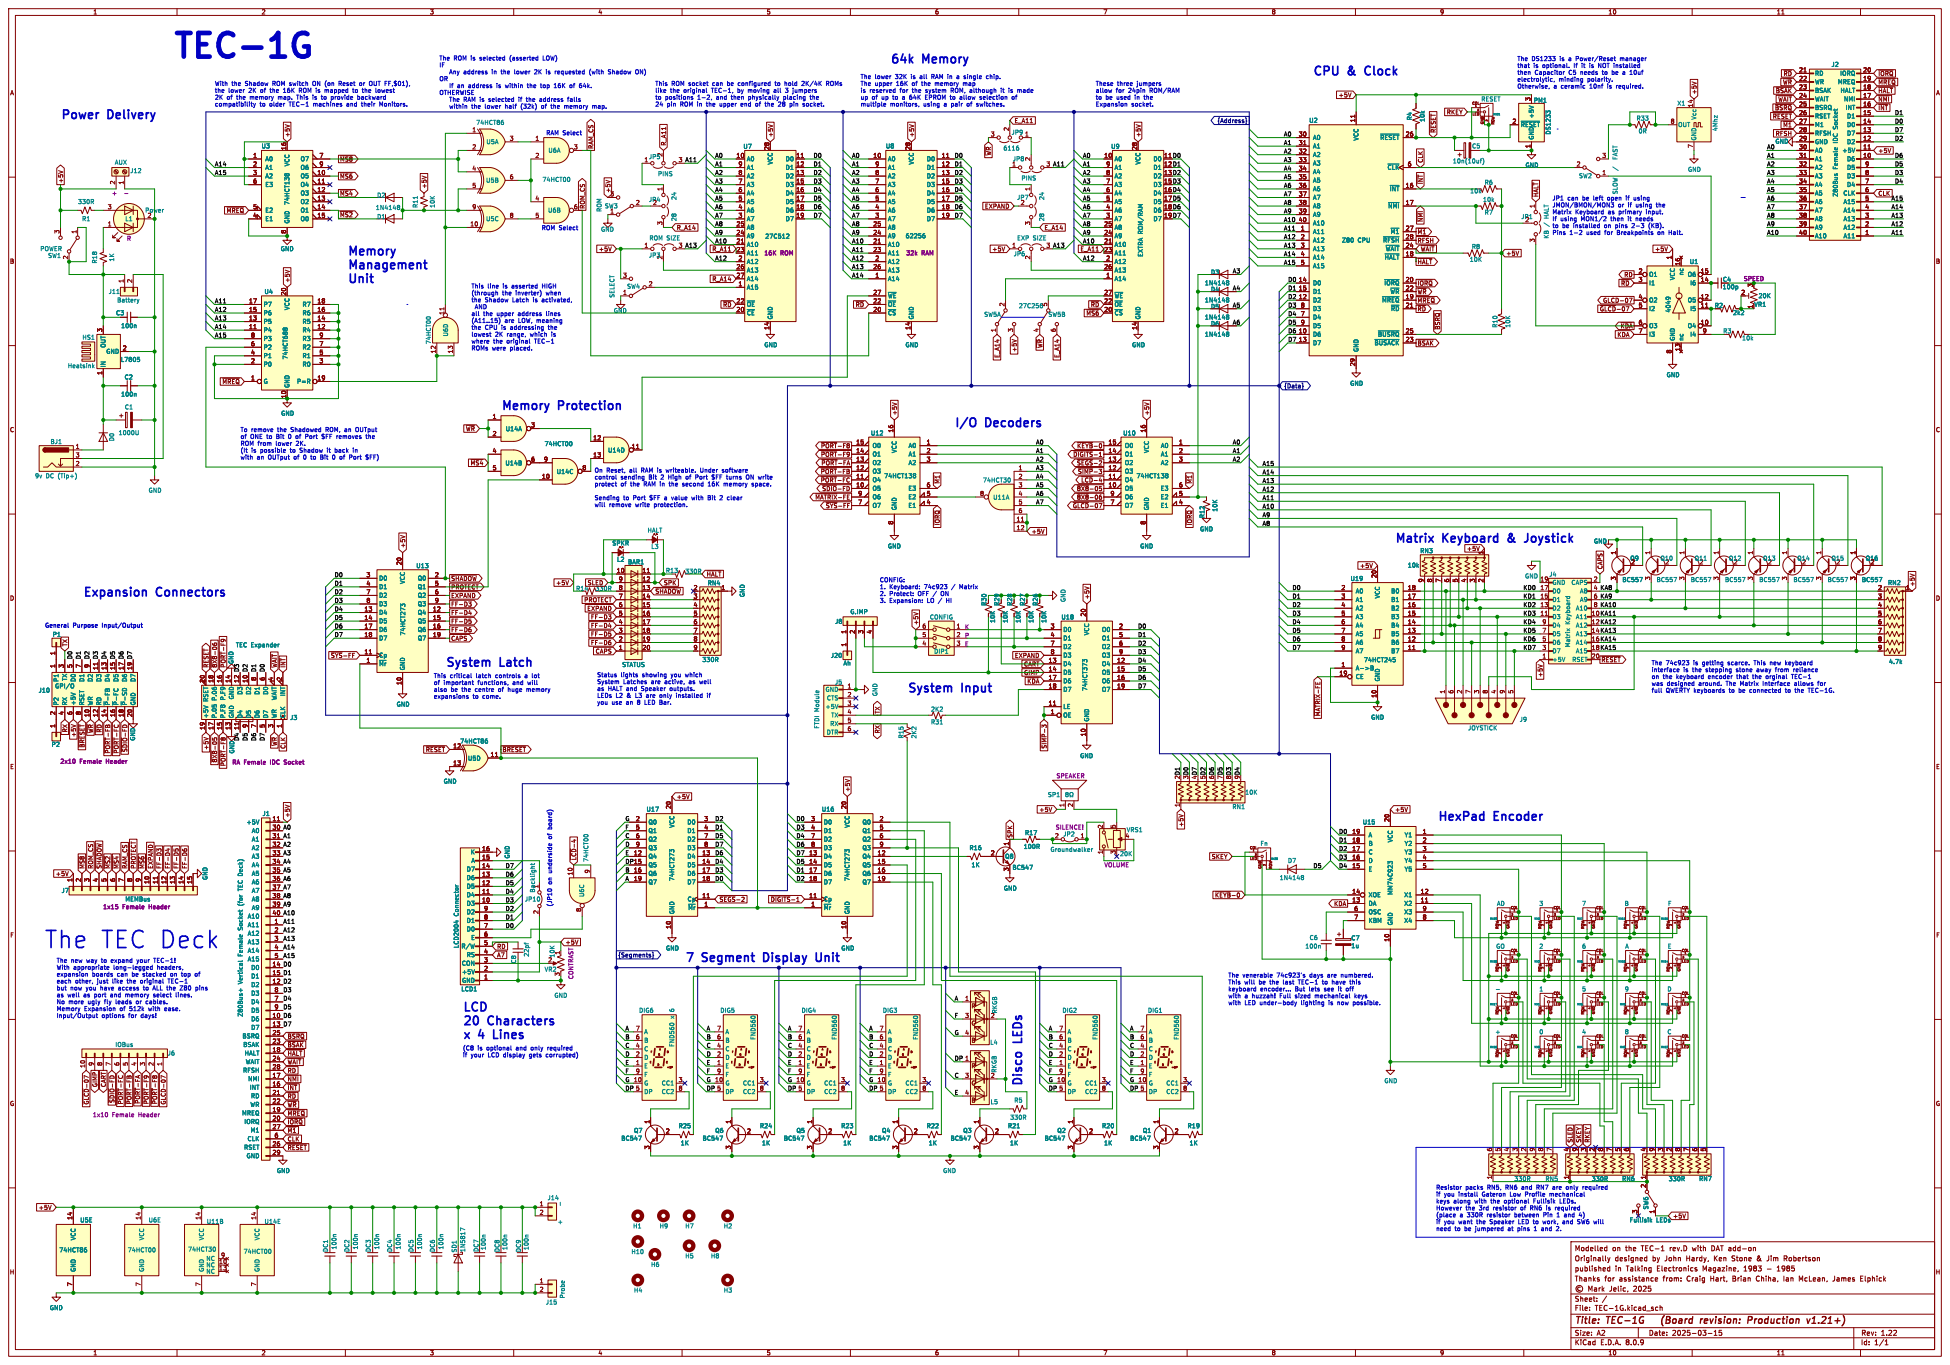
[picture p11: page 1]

24 pin ROM in the upper end of the 28 pin socket. System Latch (JP10 on underside of board)

The lower 32K is all RAM in a single chip. The upper 16K of the memory map

~{MREQ} ~{8X8}-05
With the Shadow ROM switch ON (on Reset or OUT FF,$01),
the lower 2K of the 16K ROM is mapped to the lowest 2K of the memory map. This is to provide backward

If an address is within the top 16K of 64k. OTHERWISE

These three jumpers allow for 24pin ROM/RAM

4 MX21 RESET IN
RAM Select Power Delivery

to be used in the Expansion socket. Memory

JP1 can be left open if using

If using MON1/2 then it needs

This line is asserted HIGH
the Shadow Latch is activated, AND

all the upper address lines

protect of the RAM in the second 16K memory space. Sending to Port $FF a value with Bit 2 clear will remove write protection.

J3 TEC Expander RA Female IDC Socket

J3 TEC Expander RA Female IDC Socket CLK

2x10 Female Header P1

but now you have access to ALL the Z80 pins as well as port and memory select lines. No more ugly fly leads or cables. Memory Expansion of 512k with ease.

if your LCD display gets corrupted)

~{MREQ} ~{GLCD}-07 GIMP CART

Resistor packs RN5, RN6 and RN7 are only required

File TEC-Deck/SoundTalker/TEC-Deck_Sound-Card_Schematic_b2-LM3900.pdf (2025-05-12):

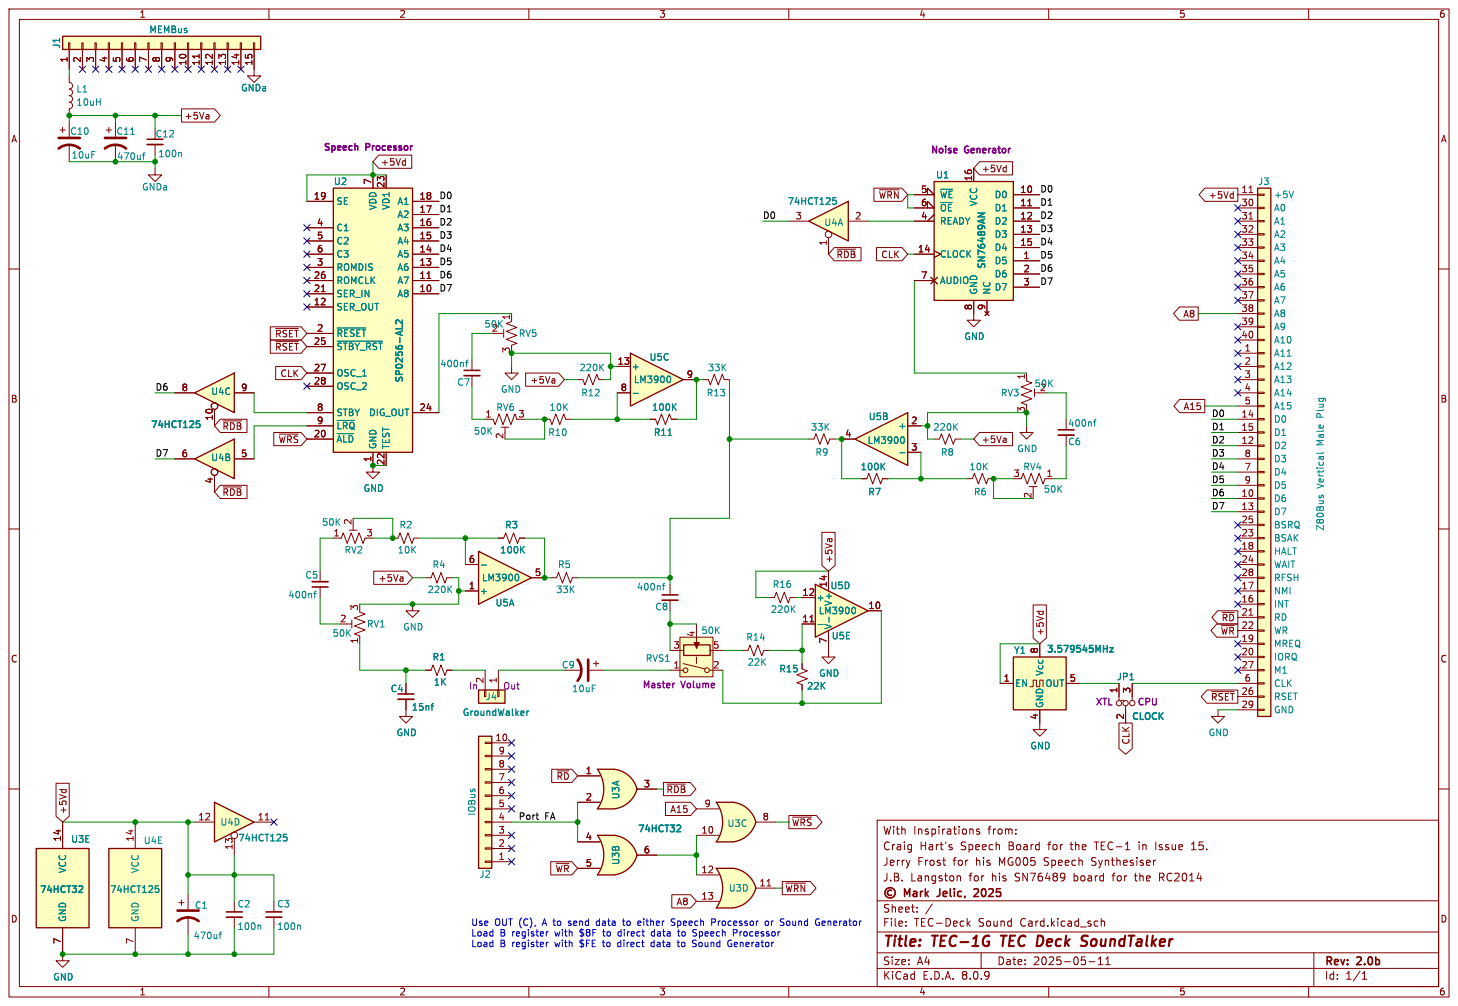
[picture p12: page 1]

1 A8 10 A7 11 SER_OUT 12 A6 13 A5 14 A4 15 A3 16 A2 17 A1 18 SE 19 ~{RESET} 2 ~{ALD} 20 SER_IN 21 TEST 22 VD1 23 DIG_OUT 24 ~{STBY_RST} 25 ROMCLK 26 OSC_1 27 OSC_2 28 ROMDIS 3 C1 4 C2 5 C3 6 VDD

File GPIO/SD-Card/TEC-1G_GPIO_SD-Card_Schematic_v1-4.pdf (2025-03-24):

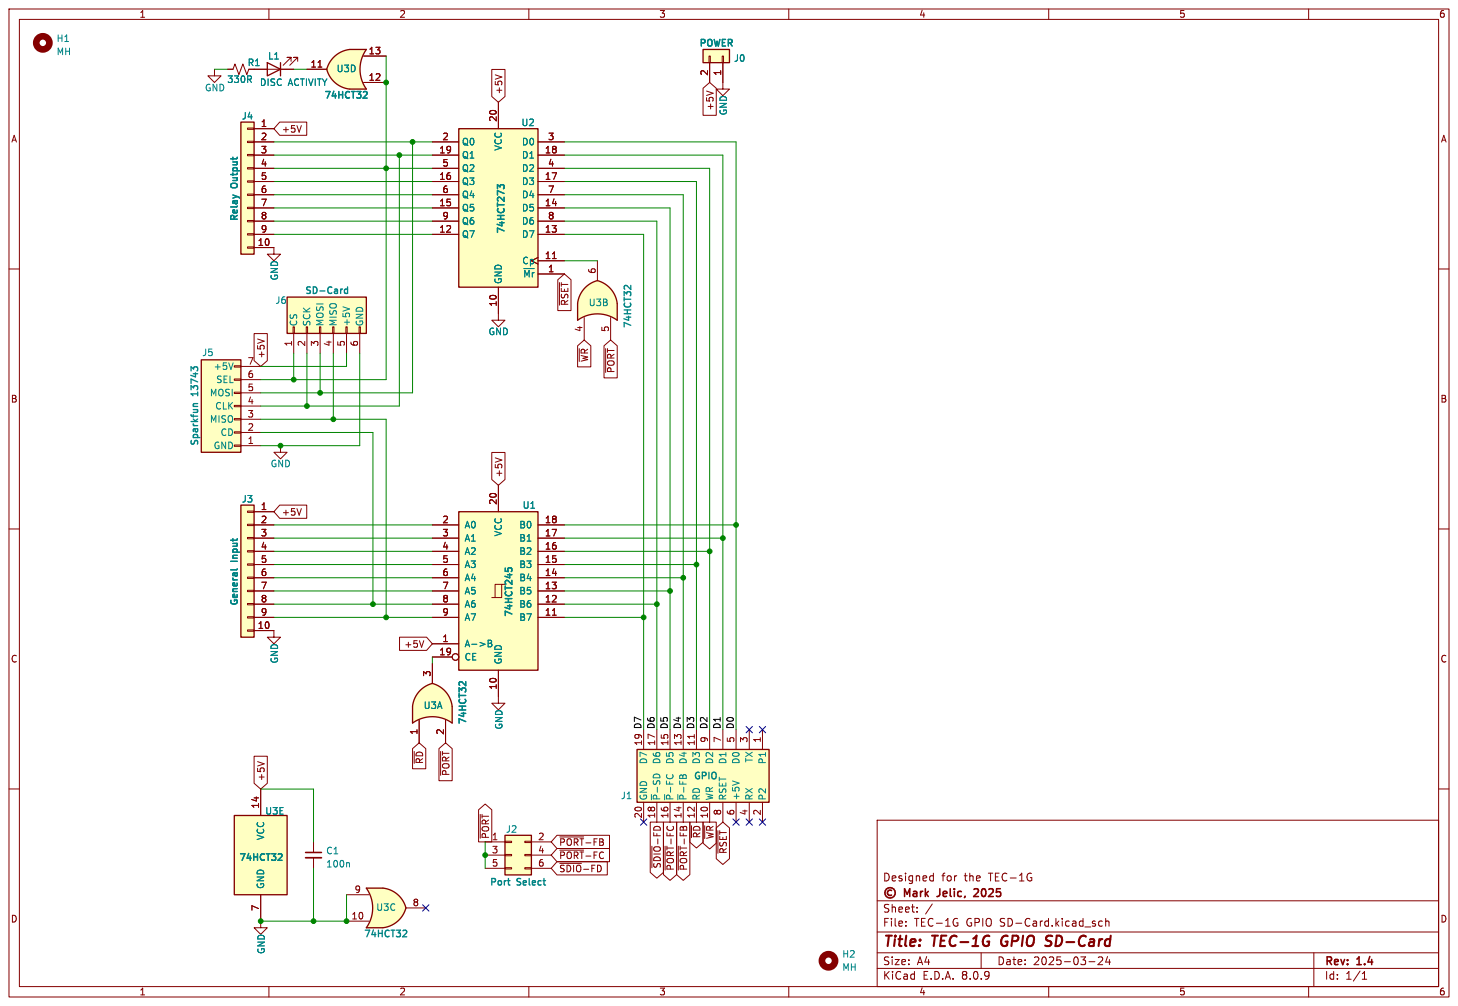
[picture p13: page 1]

Id: 1/1 Title: TEC-1G GPIO SD-Card

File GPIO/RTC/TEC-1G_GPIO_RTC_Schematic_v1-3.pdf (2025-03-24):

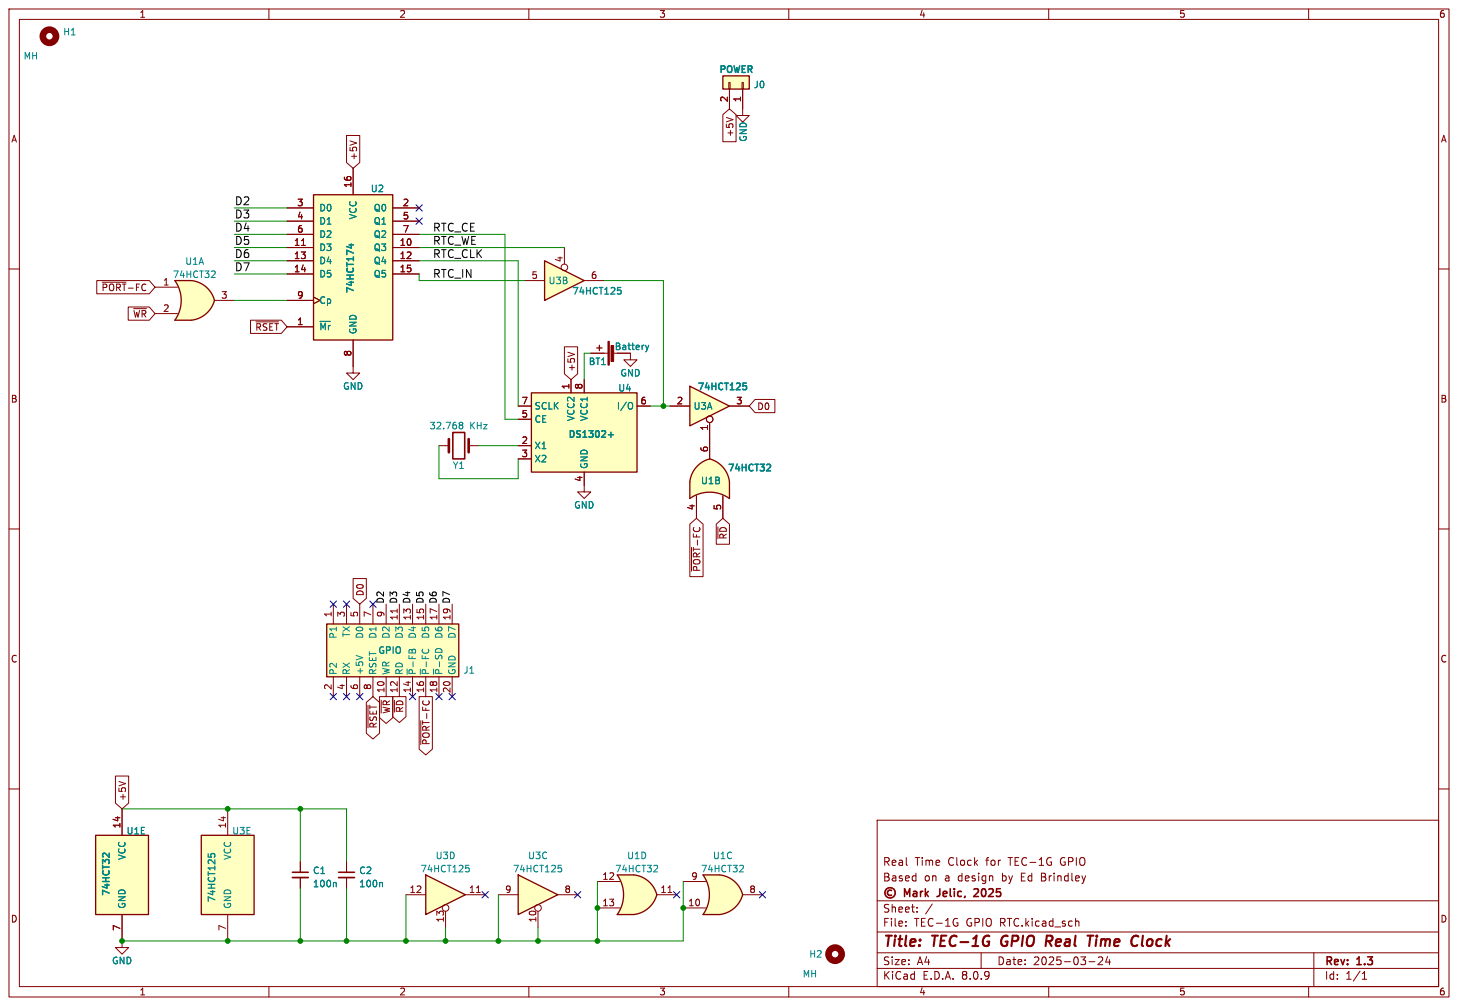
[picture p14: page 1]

Id: 1/1 Title: TEC-1G GPIO Real Time Clock

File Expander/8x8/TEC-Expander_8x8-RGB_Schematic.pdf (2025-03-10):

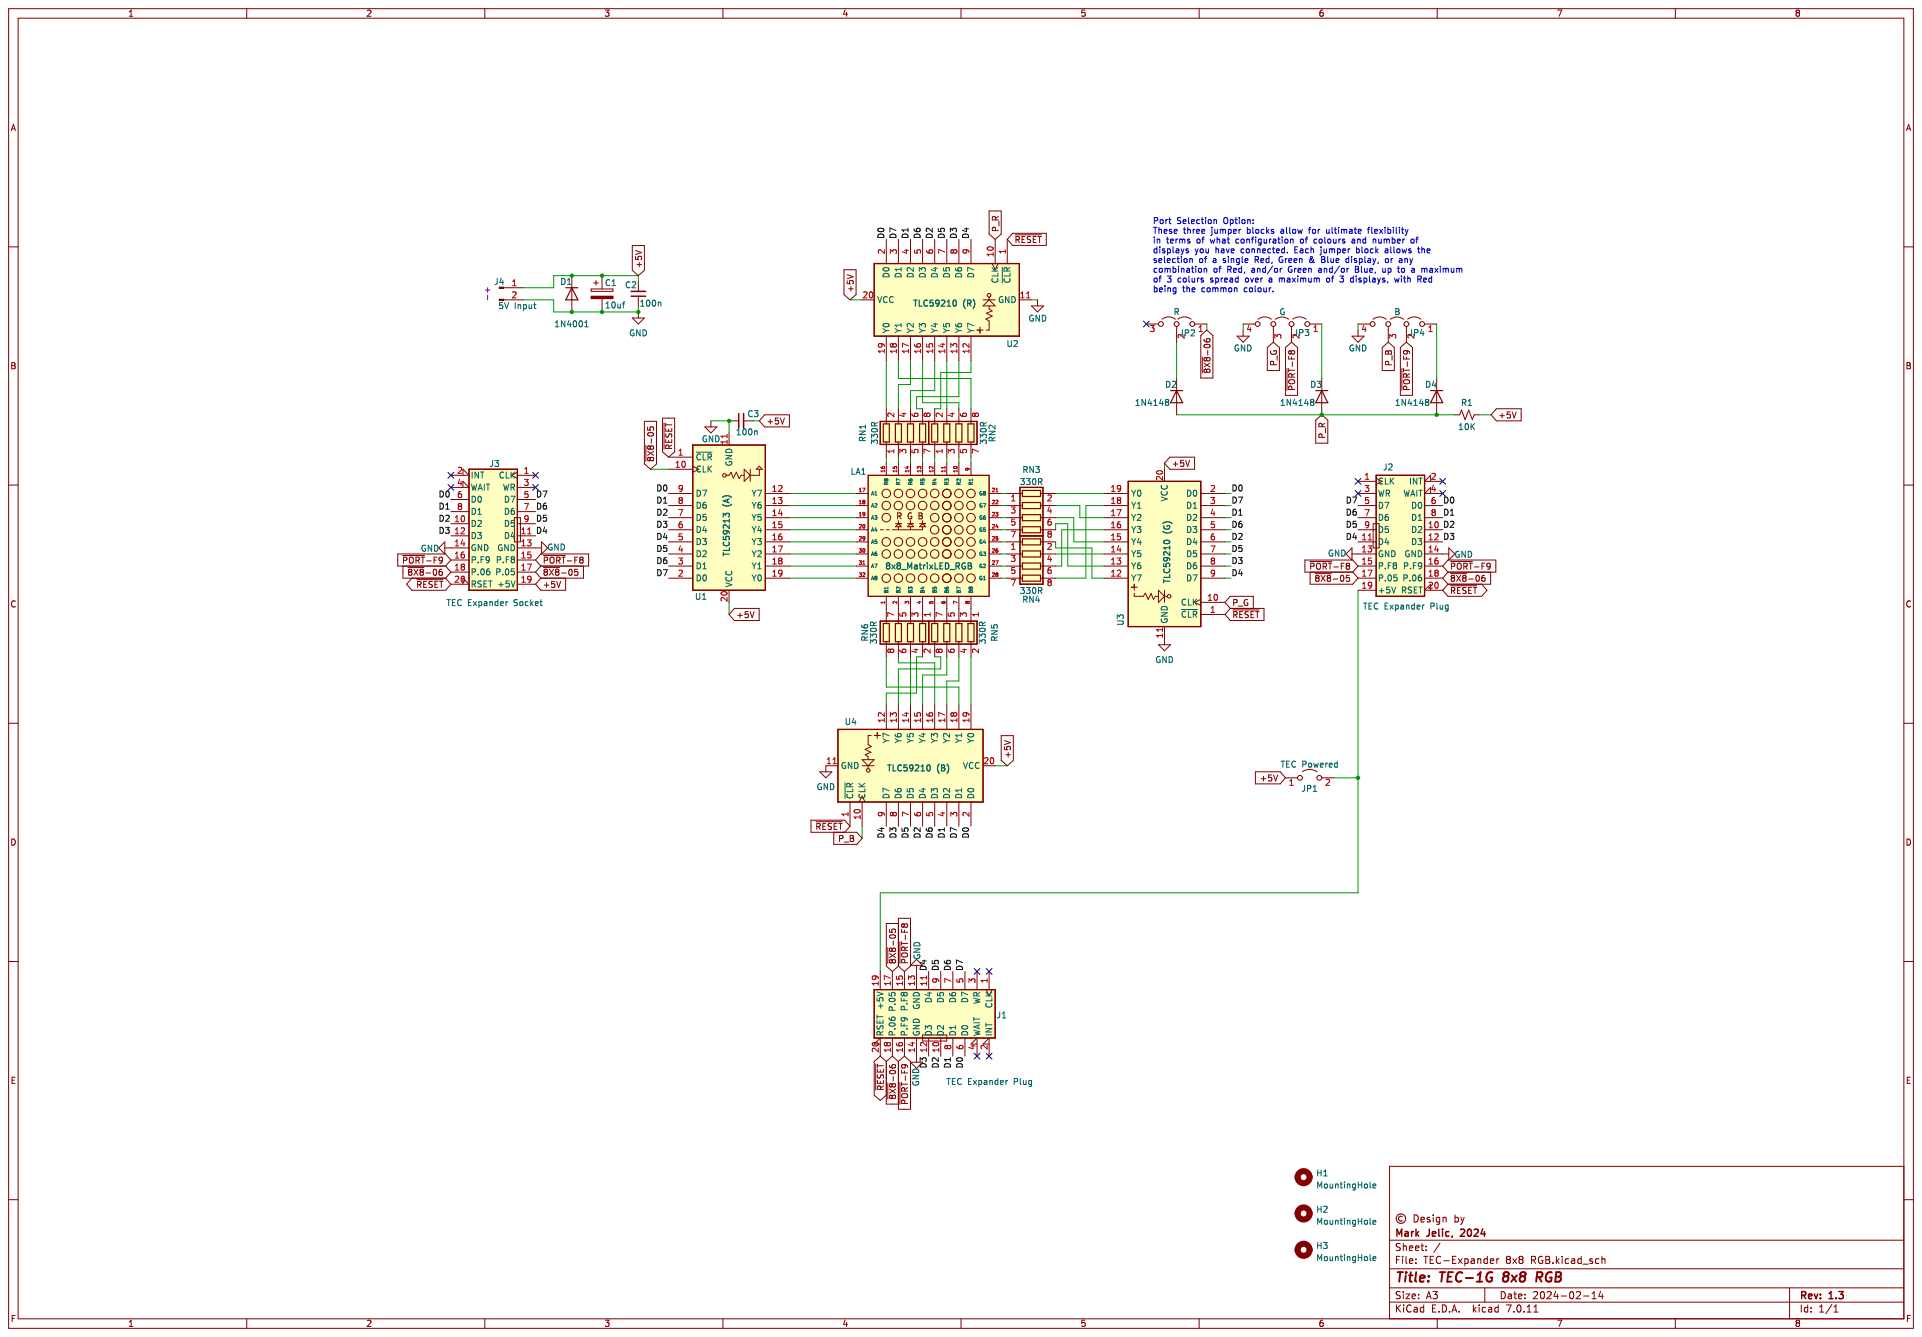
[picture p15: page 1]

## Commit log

2025-03-10 RGB 8x8 Schematic
2025-03-10 8x8 Bill of Materials
2025-03-13 Update readme with Code samples
2025-03-15 Latest Schematic
    For production boards v1.21 and above
2025-03-15 Latest Schematic v1.22
    for production boards v1.21 and above
2025-03-15 PCB Gerbers v1.22
2025-03-15 Gerbers Release
2025-03-24 Schametic and Gerber
2025-03-24 KiCAD Design Files
2025-04-05 Input Tester Gerber
2025-04-27 Delete Software/Education/Cellular.hex
    No accompanying Assembler file
2025-04-27 Delete Software/Education/tmon.hex
    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
2025-04-27 Delete Software/Education/mint.hex
    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
2025-04-27 Delete Software/Education/mon3code.hex
    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
2025-04-27 Delete Software/Education/GLCD_prg.hex
    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
2025-04-27 Delete Software/Education/GLCDterm.hex
    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
2025-04-27 Delete Software/Games/frogger.hex
    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
2025-04-27 Delete Software/Games/lander.hex
    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
2025-04-27 Delete Software/Games/IF_WUMP.hex
    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
2025-04-27 Delete Software/Games/IF_DT.hex
    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
2025-04-27 Delete Software/Games/IF_CATS.hex
    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
2025-04-27 Delete Software/Games/IF_AL2.hex
    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
2025-04-27 Delete Software/Games/IF_AL1.hex
    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
2025-04-28 Edge Cuts DXF
    For the accurate location of Mounting Holes, for anyone making 3D prints of cases and stands.
    [TEC-1G_Edge-Cuts_v1.4SE.dxf]
2025-05-16 Assembly Guide in PDF
